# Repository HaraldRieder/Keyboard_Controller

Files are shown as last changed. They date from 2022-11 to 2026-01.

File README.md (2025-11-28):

## Tasteninstrument mit 6+6 Tastatur

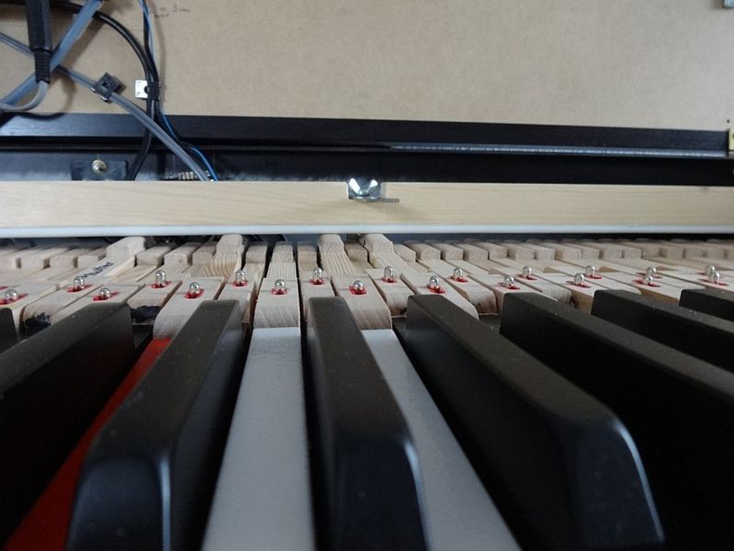
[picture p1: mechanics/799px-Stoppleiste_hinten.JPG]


Dieses Archiv enthält Anleitungen, Dokumentation und Quellcode zum Bau eines MIDI Instruments mit 6+6 Tastatur. 

Die Tastatur entspricht im vorderen Bereich der eines mechanischen Klaviers. Im hinteren Bereich kommen anstatt der Hammermechanik Bleigewichte und eine Stoppleiste zum Einsatz. Der [Bau der Tastatur ist hier](mechanics/README.md) beschrieben.

Die Elektronik basiert auf einem handelsüblichen Stummschaltesystem für Klaviere (QuietTime), das bereits Klangerzeugung enthält und MIDI-Signale ausgeben kann. Das ist für reines Klavierspiel vollkommen ausreichend. 

Ein Arduino Mega 2560 erweitert das Instrument um zusätzliche Regler, die Möglichkeit Presets für Sound Module abspeichern sowie ein Basspedal mit Diodenmatrix anschließen zu können. Die [Hardware ist hier](electronics/README.md) und die [Software und deren Bedienung hier](software/README.md) beschrieben.

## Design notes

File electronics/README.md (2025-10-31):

# Elektronik für die 6+6 Tastatur

## Module

Mit dem Hauptschalter des GT-2 mini schalten sich die komplette interne Elektronik sowie die beiden gesicherten Steckdosen auf der Rückseite mit ein und aus. Für diesen Komfort sorgt ein Triac-Relais mit Nulldurchgangsschaltung. Um es anzusteuern mussten 5V Versorgungsspannung aus dem Hauptmodul des GT-2 mini abgegriffen werden.

|Blockschaltbild|
| ----------- |
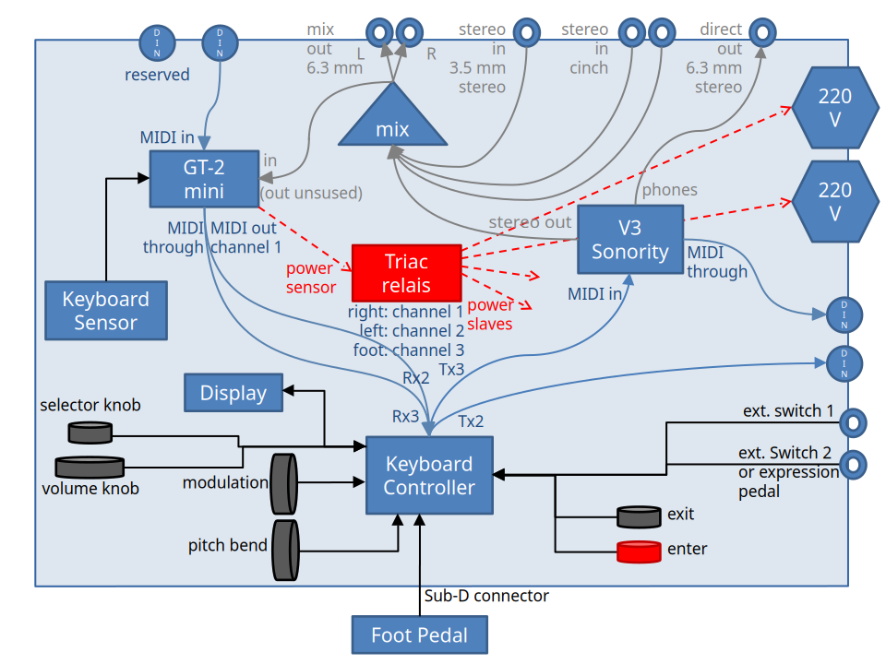
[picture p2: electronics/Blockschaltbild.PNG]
||

Das GT-2 mini Hauptmodul wird wie vorgesehen von der Tastatursensorleiste angesteuert und kann über seine Original-Bedieneinheit bedient werden. Pedalsensoren sind keine angeschlossen, denn Sustain, Sostenuto usw. werden über die selbstgebaute Steuerung realisiert. Die Tastendrücke gelangen als MIDI-Nachrichten zur selbstgebauten Steuerung, die auf einem Arduino Mega 2560 basiert. An der Steuerung hängt ein 2x20 Zeilen LCD Display, MIDI-Ein- und Ausgänge, 2 Handräder für Pitch Bend und Modulation, 2 Taster und optional extern: 1 Schalter, 1 Steuerpedal, 1 Basspedal.

Die Steuerung mischt die diversen Sensorinformationen zu den MIDI-Daten, die vom GT-2 mini empfangen worden sind, und leitet das Gesamtkunstwerk über MIDI an das interne V3 Sonority XXL Sound-Modul zwecks Hörbarmachung weiter.

Der MIDI-Eingang wird durch das GT-2 mini zur Steuerung geschleift. Diese mischt sie zum MIDI-Strom Richtung V3 hinzu. Dadurch kann das V3 als Sound-Modul über den zweiten Eingang z.B. von einem Sequenzer genutzt werden, während gleichzeitig auf der Tastatur dazu gespielt wird.

Zur Bedienung der Steuerung dienen 2 Regler (klein und groß), 2 Taster (rot und schwarz), die 2 Handräder, die Tastatur (z.B. Festlegung einer Split-Position durch Tastendruck) und optional ein Fußpedal.

Der Audio-Ausgang des V3 sowie 2 externe Stereo-Eingänge (Cinch und 3,5 mm Klinke) werden über den selbstgebauten Mischer geschleift zum externen Audio-Ausgang (2 x 6,3 mm Klinke) und gleichzeitig zum Eingang des GT-2 mini, wo das gemischte Signal über die anschließbaren Kopfhörer gehört werden kann.
Auch das Metronom des GT-2 mini kann auf diese Art benutzt werden.

Der Kopfhörer-Ausgang des V3 ist direkt nach außen geführt auf eine 6,3 mm Klinkenbuchse. Dieses Signal lässt sich außer in Kopfhörer auch in Standardeingänge einspeisen.

2024 wurde ein Ketron SD-2 durch das V3 Sonority XXL Modul ersetzt. Man konnte mit dem SD-2 keine Tremolos spielen, weil es dann Noten-Aussetzer bekam, und ein Software-Update war nicht mehr zu erwarten. Mit dem V3 kann man Tremolos spielen, so wie auf jedem mechanischen Klavier.

## Arduino Mega 2560 mit Peripherie

Zunächst einmal gab es da ein schönes Wersi-Basspedal, das anschließbar sein sollte - selbstverständlich ein 6+6 Pedal. Es hing [früher](https://github.com/HaraldRieder/Historic/index.html) an einer eigens dafür aufgebohrten Döpfer LMK3-Elektronik und enthält eine zum LMK3 passende Diodenmatrix.

|Die anzuschließende Diodenmatrix|
| ----------- |
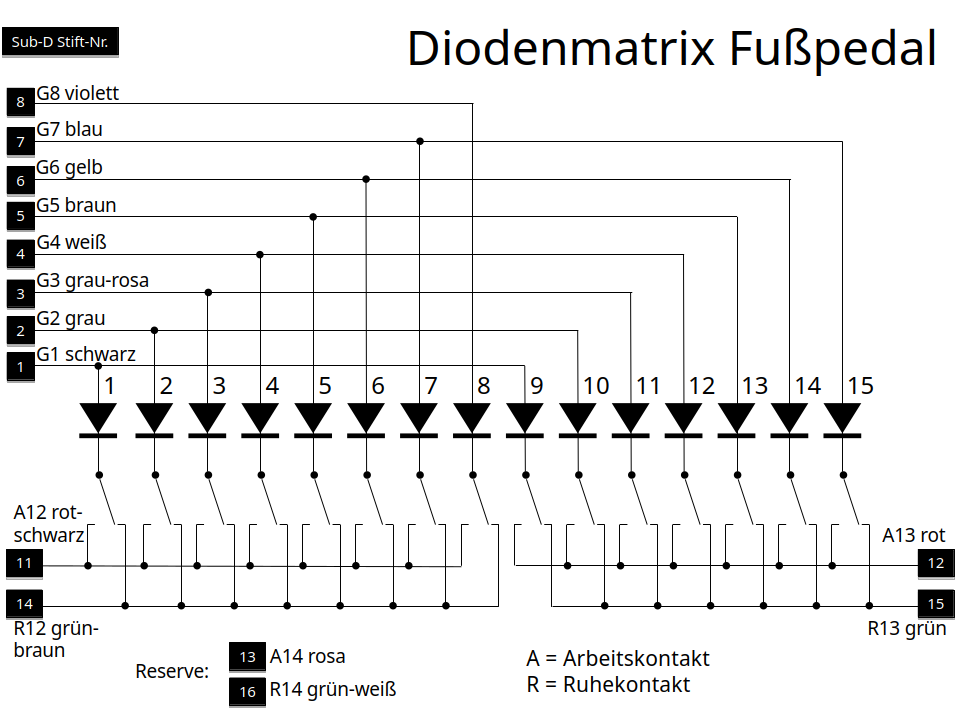
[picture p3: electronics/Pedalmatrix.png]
||

Deswegen finden sich im Schaltplan unten 6 Stück 1k Widerstände, die in LMK3-typischer Art geschaltet sind. Die Ansteuerung des Pedals gelang auf Anhieb. Ängste, dass Ladungen aus den Ausgängen eventuell nicht schnell genug übertragen werden könnten, bevor deren Wirkungen über die Eingänge der Matrix erfragt würden, erwiesen sich als unbegründet. Gegen solche Effekte hätte es aber ein Mittel gegeben: verzögertes Auslesen durch die Software.

Das Pedal wird mit einem Sub-D Stecker an das Pianogehäuse angeschlossen.

|Digitalteil mit Arduino Mega 2560|
| ----------- |
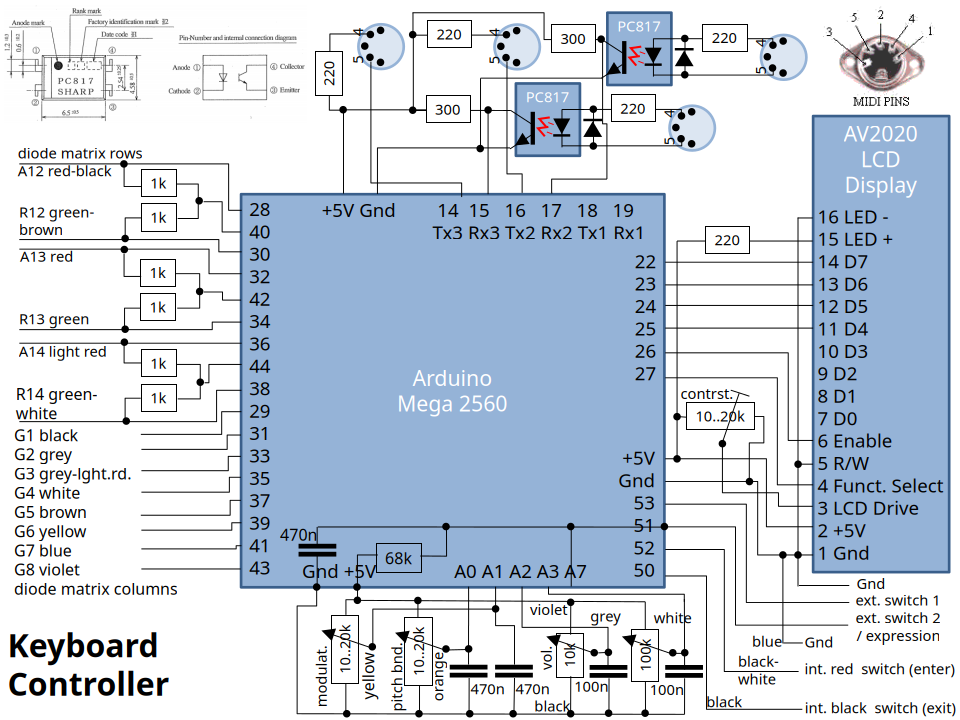
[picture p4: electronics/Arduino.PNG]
||

Über den Anschluß von MIDI-Peripherie und LCD-Anzeigen an Arduino-Boards gibt es haufenweise Anleitungen. Diese brauchen hier nicht wiederholt zu werden. Der Mega 2560 könnte bis zu 4 MIDI-Ein- und Ausgänge bedienen. Ich habe die Schaltung auf 2 MIDI-Ein- und Ausgänge ausgelegt.

_Der Digitalteil wurde ab Herbst 2015 nach und nach in Betrieb genommen. Im Frühjahr 2016 zeigten sich nach längerem Betrieb erstmals lustige Effekte: Aussetzer, falsche Tonhöhen, ganz andere Klangfarben als die eingestellte. So hören sich typischerweise MIDI-Bitfehler an, und da es in kaltem Zustand nach dem Einschalten nie Fehler gab, war klar, dass es ein Temperatureffekt sein musste. Der 220 Ohm Widerstand am MIDI-Eingang war etwas zu groß bemessen für den verwendeten PC 817 Optokoppler. Die Reparatur erfolgte durch Austausch des PC 817 gegen ein anderes Exemplar. Alternativ hätte man den Widerstand verkleinern können._

Die Handräder werden zwar von relativ niederohmigen Potentiometern abgegriffen, sind allerdings über lange Leitungen mit der Steuerung verbunden. Die 470 nF Glättungskondensatoren sind deswegen tatsächlich erforderlich! Ohne sie bekäme die Software von der Hardware nerviges Gezappel.

Für die internen Taster und externen Schalter werden Pullup-Widerstände eingesetzt. Damit gab es noch nie ein falsches Signal.

Ein externer Anschluss ist ein Zwitter. Sowohl ein analoger (A7) als auch ein digitaler Eingang (51) teilen sich ihn.
Während sonst Arduino-interne Pullup-Widerstände zum Einsatz kommen, ist hier ein externer Pullup-Widerstand Rp = 68k verbaut.
Der Grund: es sollte ein vorhandenes Schwellerpedal angeschlossen werden. Das Schwellerpedal enthält ein 450k logarithmierendes Poti.
Die Software soll nicht linearisieren müssen. Das Poti liefert einen exponentiell vom Weg x abhängigen Widerstand R(x).
Durch den Spannungsteiler aus Pullup Rp und R ergibt sich eine Eingangsspannung U(R) ~ R/(R+Rp).
Durch geschickte Wahl von Rp kann man die verketteten nichtlinearen Funktionen R(x) und U(R)
gegeneinander ausspielen und so die Gesamtfunktion U(R(x)) = U(x) einigermaßen linear bekommen.
Die Entscheidung, ob der Anschluss für kontinuierliche oder diskrete MIDI Controller oder beide Arten zugleich verwendet wird, fällt erst in der Software.

Später wurden 2 Potentiometer auf der rechten Seite der Frontblende hinzugefügt. Beide sind an analoge Eingänge angeschlossen.
Eines davon regelt immer die Gesamtlautstärke.

Es sind noch 3 analoge Eingänge unbeschaltet.

Das nächste Bild zeigt den Teil der Elektronik, der am aufklappbaren Deckel des Pianogehäuses hängt:

- links noch mit Ketron SD-2 Sound-Modul
- rechts Steuerung mit Arduino Board. Der Klinkenstecker kommt von den beiden Mono-Klinkenbuchsen für die externen Schalter. Der graue Stecker rechts führt zur Pedalanschlussbuchse (Sub-D).
- oben 2x20 zeilige LCD-Anzeige
- rechts neben dem Arduino pressspänerne Leere: später hat sich an diese Stelle der Audio-Mischer hinzugesellt.

|Elektronik im Deckel|
| ----------- |
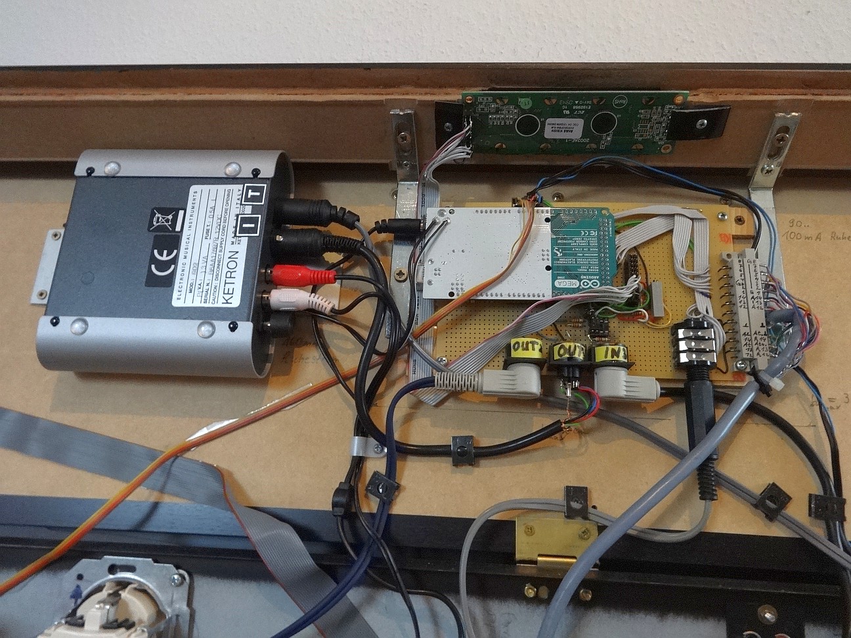
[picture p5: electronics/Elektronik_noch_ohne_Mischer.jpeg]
||

Viel mehr ist zum Digitalteil nicht zu sagen, den Rest muss die Software erledigen.

## Audio-Mischer

Der Audiomischer hat zunächst ein eigenes Analognetzteil mit Transformator und Brückengleichrichter bekommen, um nicht auf unerwünschte Weise mit dem Digitalgedöns verbunden sein zu können (Brummschleife!). Ein 7809 Spannungsregler regelt auf 9V, was für viele Operationsverstärker ausreicht.

Es kommt ein Operationsverstärker TLE2072 zum Einsatz, der rauschärmer als ein TL072 sein soll.

|Schaltplan Audio-Mischer|
| ----------- |
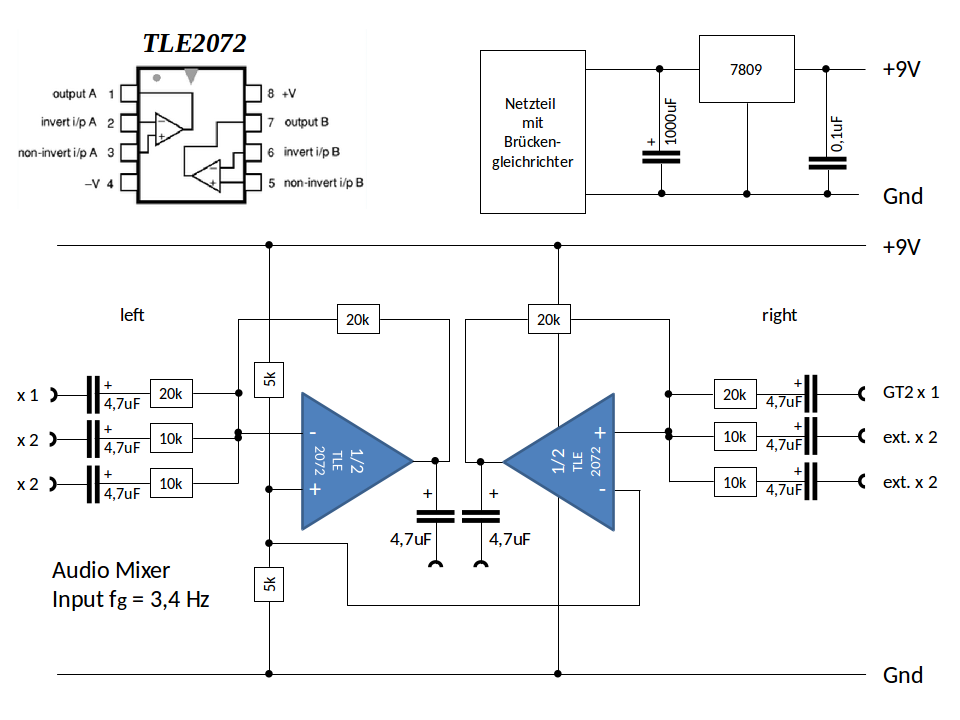
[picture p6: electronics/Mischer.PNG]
||

Der Mischer "verstärkt" den für das MIDI-Modul vorgesehenen Stereo-Kanal mit dem Faktor 1. Der Lautstärkeregler des V3 ist immer voll aufgedreht. Die beiden externen Stereo-Kanäle werden mit einem Faktor 2 verstärkt. Das soll es erlauben, das interne Sound-Modul bei Bedarf zu übertönen.
Der Stereo-Ausgang ist nach außen geführt und auf den Eingang des GT-2 mini gelegt. Dort darf man das Eingangssignal nicht ganz aufdrehen, weil es sonst zu Übersteuerungen kommt.

|Der Mischer entsteht|
| ----------- |
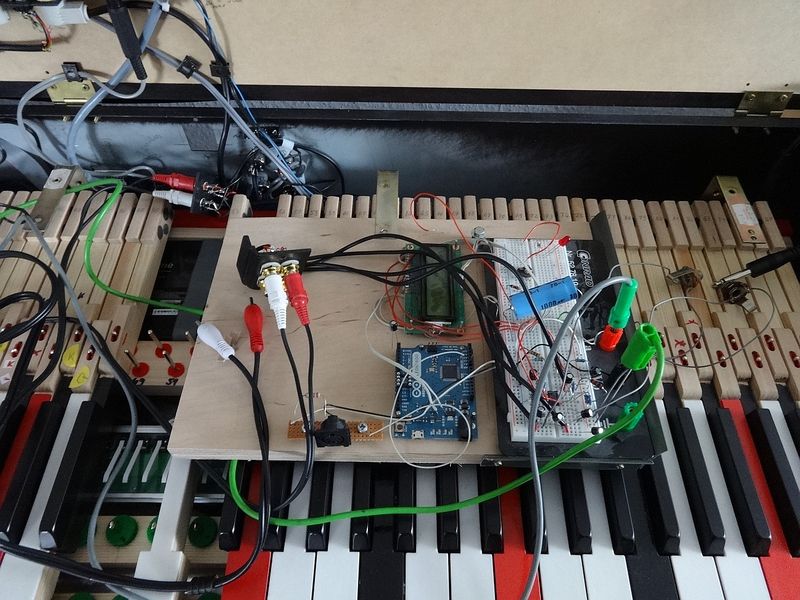
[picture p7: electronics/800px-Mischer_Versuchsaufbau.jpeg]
||

Der Mischer wurde zunächst auf einem Experimentierbrett aufgebaut. Dabei gab es keine Überraschungen, außer dass ich in einem Anfall von geistiger Umnachtung zuerst den Spannungsregler nicht eingeplant hatte und mit entsprechendem Gebrumme bestraft wurde.

|Master-Slave-Switch und Mischer-Netzteil|
| ----------- |
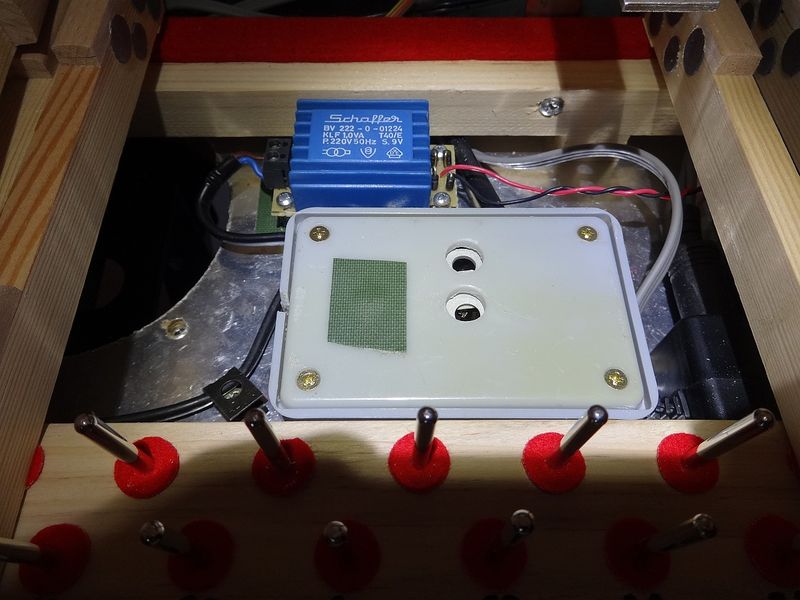
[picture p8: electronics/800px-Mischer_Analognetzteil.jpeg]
||

Das Bild zeigt das graue Gehäuse des Master-Slave-Netzschalters und das daran angeschlossene Netzteil für den Mischer mit seinem blauen Transformator und 4 1N4006 Dioden in Brückenschaltung.

## Alles zusammen

|Elektronik untergebracht, noch ohne Mischer|
| ----------- |
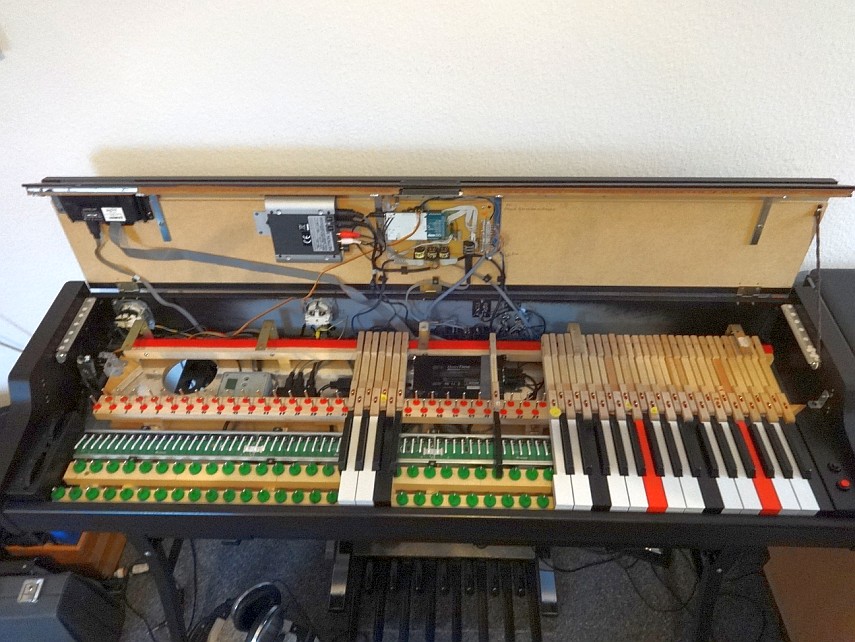
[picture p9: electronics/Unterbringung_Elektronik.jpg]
||

|Mischer und neue Bedienelemente an der Frontblende|
| ----------- |
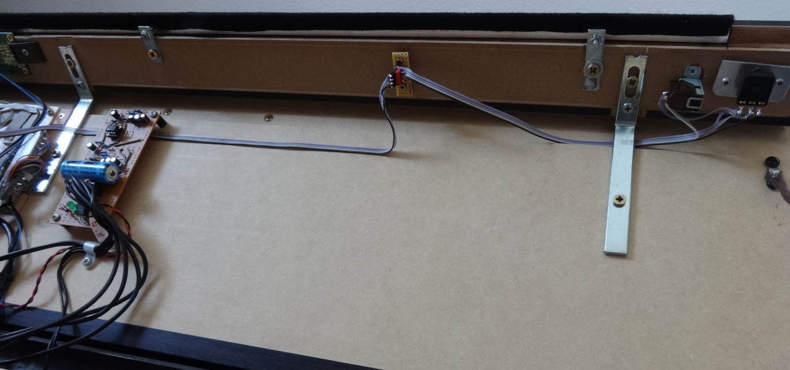
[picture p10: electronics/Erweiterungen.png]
||

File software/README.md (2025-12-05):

# Weichware

Der Quellecode für das Arduino Mega 2560 Board ist [auf GitHub](https://github.com/HaraldRieder/Keyboard_Controller) verfügbar.

Das Board verfügt über 8 KByte Hauptspeicher (RAM) und 4 KByte EEPROM,
in dem die duch den Bediener vorgenommenen Einstellungen dauerhaft gespeichert werden.

Aktuell wird davon ausgegangen, dass ein V3 Sonority XXL angesteuert werden soll (`SonorityXXL.h`).
Davor war die Software zur Steuerung eines Ketron SD2 ausgelegt (`KetronSD2.h`).

Der Quellcode lässt sich mit vertretbarem Aufwand an andere MIDI Module anpassen.
Nicht jedes Modell bietet dieselben Funktionen an,
doch die Unterstützung vieler Standard-MIDI-Funktionen ist heutzutage weit verbreitet.
Unterschiede finden sich naturgemäß im Sysex-Bereich.

## Initialisierung

Aktuell werden 35 Presets unterstützt.
Wird ein Preset gelesen und dabei nicht der "magische" 32-Bit-Wert `2e031fe5` gefunden, dann wird es mit Standardeinstellungen initialisiert:
das Pedal arbeitet als Steuerpedal (Controller) und der Tastaturbereich ist nicht geteilt (Split).
Auf diese Weise kann ein neues Board in Betrieb genommen werden.

## Backups

Es gibt keine Backup-Funktion (z.B. MIDI-Dumps).
Als primitiver Ersatz werden die Einstellungen nach dem Einschalten auf USB in menschenlesbarem Format ausgegeben.
Um sie zu sehen benötigt man eine Arduino IDE mit seriellem Monitor.
Das Arduino-Board muss an den Rechner per USB-Kabel angeschlossen sein.
Die Baud-Rate muss auf **500000** eingestellt sein.
Dann zeigt sich nach dem Einschalten im seriellen Monitor etwas wie im folgenden Beispiel.

      Global_Settings
       Velocity map: 77
      Presets
      1 Reverb type: Room 1, Effect type: Chorus 1
        Keyboard:   Piano / Class Gnd Res
          Transpose: 0, Fine tune: 0, Volume: 100, Stereo pan: 64, Reverb send: 10, Effects send: 0
          Cutoff frequency: 33, Resonance: 0, Attack: 64, Decay: 64, Release: 64
          Vibrato rate: 64, Depth: 0, Delay: 64, Portamento time: 1
          Modulation wheel: modulation, Pitch wheel: pitch bend, External switch: sustain, External pedal: cutoff frq
      2 Reverb type: Room 2, Effect type: Chorus 3
        Keyboard:   E-Pno / MK1
          Transpose: 0, Fine tune: 0, Volume: 84, Stereo pan: 64, Reverb send: 5, Effects send: 39
          Cutoff frequency: 82, Resonance: 0, Attack: 64, Decay: 64, Release: 64
          Vibrato rate: 64, Depth: 0, Delay: 64, Portamento time: 1
          Modulation wheel: modulation, Pitch wheel: pitch bend, External switch: sustain, External pedal: (none)
      ...
      35 Reverb type: Room 1, Effect type: Chorus 1
        Foot Pedal:   Bass / Up Jz no fingr
          Transpose: 2, Fine tune: -2, Volume: 110, Stereo pan: 64, Reverb send: 0, Effects send: 0
          Cutoff frequency: 64, Resonance: 0, Attack: 64, Decay: 64, Release: 74
          Vibrato rate: 64, Depth: 0, Delay: 64, Portamento time: 255
          Modulation wheel: (none), Pitch wheel: (none), External switch: (none), External pedal: (none)
        Keyboard Left:   Organ / __853____ slow
          Transpose: 12, Fine tune: 0, Volume: 55, Stereo pan: 64, Reverb send: 15, Effects send: 0
          Cutoff frequency: 22, Resonance: 0, Attack: 64, Decay: 64, Release: 64
          Vibrato rate: 64, Depth: 0, Delay: 64, Portamento time: 255
          Modulation wheel: modulation, Pitch wheel: pitch bend, External switch: sustain, External pedal: (none)
        Keyboard Right:   Organ / 8________ slow
          Transpose: -12, Fine tune: 2, Volume: 100, Stereo pan: 64, Reverb send: 15, Effects send: 0
          Cutoff frequency: 127, Resonance: 0, Attack: 64, Decay: 64, Release: 64
          Vibrato rate: 64, Depth: 0, Delay: 64, Portamento time: 255
          Modulation wheel: modulation, Pitch wheel: pitch bend, External switch: sustain, External pedal: inv.expres
        Keyboard Right Layer:   Organ / 6876_____ fast
          Transpose: -12, Fine tune: 0, Volume: 127, Stereo pan: 64, Reverb send: 15, Effects send: 0
          Cutoff frequency: 64, Resonance: 0, Attack: 64, Decay: 64, Release: 64
          Vibrato rate: 64, Depth: 0, Delay: 64, Portamento time: 255
          Modulation wheel: modulation, Pitch wheel: pitch bend, External switch: sustain, External pedal: expression
      Demian ready

## Latenzen

Nach dem Verlassen der globalen Einstellungen (siehe Bedienung) werden kurz Zeiten eingeblendet, die zur Latenz beitragen:

- Loop delay: die Zeit, die das Arduino Board für seine eigenen Geschäfte benötigt, bevor es wieder die Kontrolle an den Anwendungscode abgibt
- Pedal scan: die Zeit, die für das einmalige Ermitteln der Stellung der 15 Pedaltasten benötigt wird

Die Zeiten werden zyklisch gemessen. Angezeigt werden die jeweils gemessenen Maximalwerte. In Summe bewegen sie sich um oder unter 1 ms.

Zum Vergleich: bei 31250 baud (Bit/s) kann man über eine klassische MIDI-Verbindung in 1 ms wieviel Note-on oder Note-off Nachrichten übertragen?
Jede solche Nachricht benötigt 3 Byte. Jedes Nutz-Byte wird dank Start- und Stopbit auf 10 Bit vergrößert, wodurch jede solche Nachricht 30 Bit lang wird.
Also kann man in einer Millisekunde 0,001 x 31250 / 30 = eine einzige MIDI-Nachricht übertragen.

Bei kontinuierlichen Reglern kann es aufgrund von Rauschen (mechanisch, thermisch) zu häufigen Änderungen der digitalisierten Werte kommen,
die das Potential dazu haben, einen MIDI-Kanal zu verstopfen. Die Software verfügt über Mechanismen zur Rauschunterdrückung.

## Bedienung

### Bedienelemente

- schwarzer Taster: Durchwechseln, Ausgang, Abbruch
- roter Taster: Eintritt, Bestätigen
- kleiner Regler: Auswahl von Parameterwerten
- großer Regler: Gesamtlautstärke
- Tonhöhenrad: zur Beeinflussung der Tonhöhe (Pitch bend) oder je nach Preset auch anderer MIDI-Controller. Wenn ein Preset editiert wird, dann werden mit diesem Rad Parameterwerte eingestellt.
- Modulationsrad: steuert den Vibratoeffekt (Modulation) oder je nach Preset auch andere MIDI-Controller. Wenn ein Preset editiert wird, dann werden mit diesem Rad einzustellende Parameter ausgesucht.
- Pedal: ein 15-Tastenpedal kann wahlweise als Basspedal oder zur Steuerung von MIDI-Controllern verwendet werden.
- externer Schalter: standardmäßig für ein Haltepedal (Sustain) vorgesehen, kann je nach Preset auch andere MIDI-Controller beeinflussen.
- externer Regler: standardmäßig für den Ausdruck vorgesehen (Expression), kann je nach Preset auch andere MIDI-Controller beeinflussen.

Viele MIDI-Module interpretieren *Expression* einfach als Lautstärke. Manchmal lässt sich etwas anderes einstellen.

### Einschalten

Beim Einschalten wird für wenige Sekunden der noch freie Speicher (RAM) angezeigt.

Außerdem wird automatisch ermittelt, ob der externe Schalter als Öffner oder Schließer arbeitet.
Damit dies gelingen kann, sollte der Schalter beim Einschalten in seiner Ruheposition sein.
Das Ergebnis wird ebenfalls für wenige Sekunden angezeigt.

Nach dem Einschalten wird das Preset geladen und angezeigt, das der Stellung des kleinen Reglers entspricht.

### Spielmodus und globale Einstellungen

Mit dem schwarzen Taster kann zyklisch gewechselt werden zwischen

- Spielen von Presets, mit den zuvor frei gewählten und gespeicherten Einstellungen und gegebenenfalls Keyboard-Split und Fußpedal
- Spielen von Sounds, wie sie bereits der Hersteller im V3 Modul festgelegt hat
- Globale Einstellungen

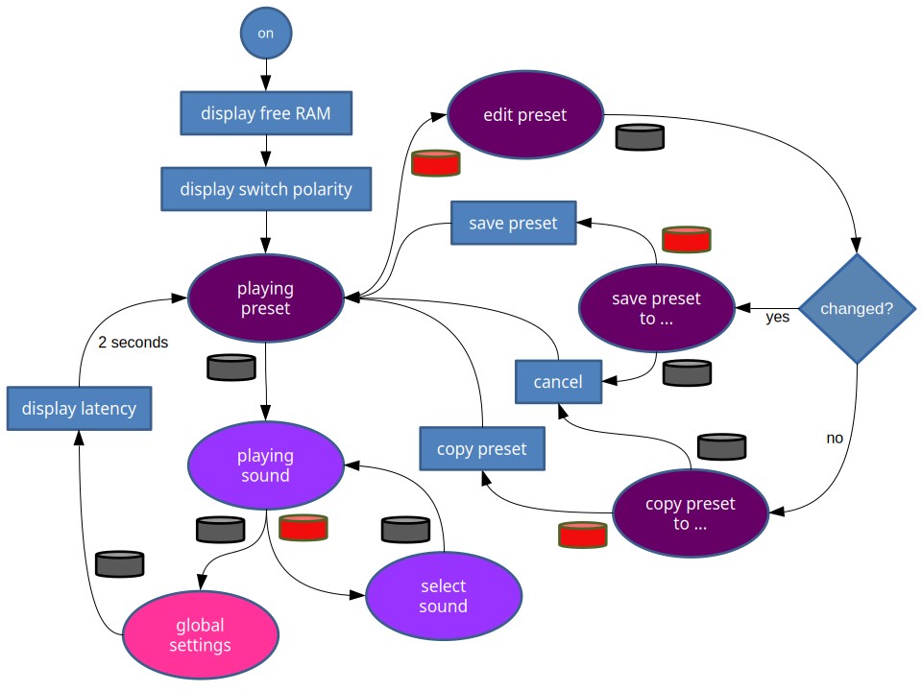
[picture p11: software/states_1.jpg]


Aus dem Modus *Spielen von Presets* gelangt man in den Editier-Modus durch Drücken des roten Tasters, den man mit dem schwarzen Taster wieder verlassen kann.

Wurde das Preset verändert, so wird man gefragt, ob man das Preset speichern möchte. Standardmäßig wird es an die aktuelle Position gespeichert. Mit dem Modulationsrad lässt sich jedoch eine anderes Ziel wählen, das heißt, dass das editierte Preset nicht geändert wird sondern ein anderes Preset überschrieben wird. Der rote Taster bestätigt das Speichern. Mit dem schwarzen Taster lassen sich die Änderungen verwerfen.

Wurde das Preset nicht verändert, so wird man gefragt, ob man das Preset kopieren möchte. Mit dem Modulationsrad lässt sich das Ziel für die Kopieraktion wählen. Der rote Taster bestätigt das Kopieren. Mit dem schwarzen Taster lassen sich die Änderungen verwerfen.

Nochmaliges Drücken des schwarzen Tasters wechselt in den Modus _Spielen von Sounds_. Mit dem kleinen Regler wird nun der Sound innderhalb der Bank gewählt. 

Nach Drücken des roten Tasters gelangt man in den Modus _Auswahl eines Sounds_ und Modulations- und Tonhöhenrad dienen zur Auswahl von Bank bzw. Sound. 
Dabei blinkt die Anzeige. Drücken des schwarzen Tasters wechselt zurück in den Modus _Spielen von Sounds_, das Blinken hört auf.

### Editieren eines Preset

Ein Preset besteht aus vielen Parametern, die in Gruppen zusammengefasst sind. Die Gruppe lässt sich mit dem Modulationsrad auswählen. Es gibt diese Gruppen:

- Gemeinsame Parameter
- Tastatur-Parameter (wenn Tastatur nicht geteilt)
- Pedal-Parameter (nur im Pedalmodus *Bass*)
- Parameter für linken Tastaturabschnitt (nur wenn Tastatur geteilt)
- Parameter für rechten Tastaturabschnitt (nur wenn Tastatur geteilt)
- Parameter für rechten Tastaturabschnitt (zweite Klangschicht, nur wenn Tastatur geteilt)

Die Parameter in den Gruppen werden mit dem Modulationsrad ausgewählt. Parameterwerte können mit dem Tonhöhenrad oder dem Regler eingestellt werden.

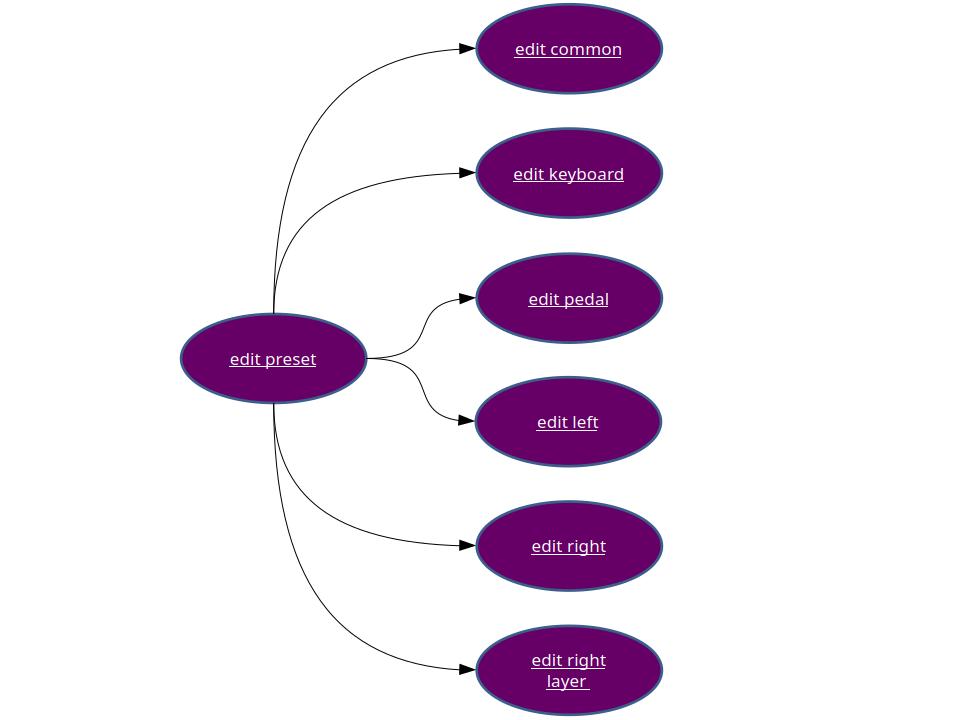
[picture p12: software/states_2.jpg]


#### Gemeinsame Parameter

- Tastaturtrennung links/rechts (Split-Position). Die Position lässt sich auch durch Drücken einer Taste der Tastatur einstellen. Zum Aufheben der Trennung muss das Modulationsrad oder der Regler bemüht werden.
- Pedal-Modus: Wahl zwischen Bass- oder Fußschalter-Modus
- Typ des 1. Effektgeräts (FX1)
- Typ des 2. Effektgeräts (FX2)

#### Tastatur-Parameter, Pedal-Parameter, Parameter für Tastaturabschnitte

Diese Gruppen enthalten immer denselben Satz an Parametern:

- Sound Bank
- Sound (MIDI-Programm-Nummer)
- Transponierung in "Halbton"-Schritten
- Feinstimmung in Cent-Schritten
- Relative Lautstärke
- Stereo-Panorama
- Hall (1. Effektgerät)
- Effekt (2. Effektgerät)
- Tiefpass-Frequenz (Cutoff)
- Filter-Resonanz
- Ankling-Geschwindigkeit (Attack)
- Abkling-Geschwindigkeit vor dem Loslassen der Taste (Decay)
- Abkling-Geschwindigkeit nach dem Loslassen der Taste (Release)
- Vibrato-Frequenz (Rate)
- Vibrato-Stärke (Depth)
- Vibrato-Verzögerung (Delay)
- Portamento-Zeit. Portamento muss über ein Bedienelement explizit eingeschaltet werden.
- Funktion der Pitch-Bend-Rads:
    - keine
    - Pitch Bend
    - Portamento-Einsatz
- Funktion des Modulations-Rads
    - keine (none)
    - Modulation
    - Tiefpass-Frequenz (Cutoff)
    - Filter-Resonanz
    - Expression
    - Expression invertiert
- Funktion des externen Schalters
    - keine (none)
    - Haltepedal (Sustain)
    - Sostenuto
    - Weich (Soft)
    - Portamento an/aus
- Funktion des externen Reglers
    - keine (none)
    - Modulation
    - Tiefpass-Frequenz (Cutoff)
    - Filter-Resonanz
    - Expression
    - Expression invertiert

Die *keine* Funktion kann z.B. dazu genutzt werden, ein Haltepedal nur auf den rechten Tastaturbereich wirken zu lassen,
wenn der linke Bereich dem Bassspiel dienen soll.

Die Funktion _Expression invertiert_ ist speziell für den rechten Tastaturbereich gedacht, der 2 Kanäle gleichzeitig ansteuert.
Wenn ein Kanal mit _Expression_ und der andere mit _Expression invertiert_ vom selben Regler
gesteuert wird, lassen sich damit Überblendungen realisieren.

### Pedal

Das Pedal dient entweder zum Bassspiel, wenn es in den Preset-Einstellungen so definiert ist, oder zur Steuerung der Funktionen, die auf dem Bild gezeigt sind. Soft, Sustain (Haltepedal) und Sostenuto sind von Klavieren her bekannt. Wenn im Preset-Modus ein Tastatursplit aktiv ist, dann können Sustain und Sostenuto für linken und rechten Klaviaturbereich getrennt gesteuert werden. Unterstützung von Portamento hängt vom gewählten Sound des angesteuerten MIDI-Moduls ab.

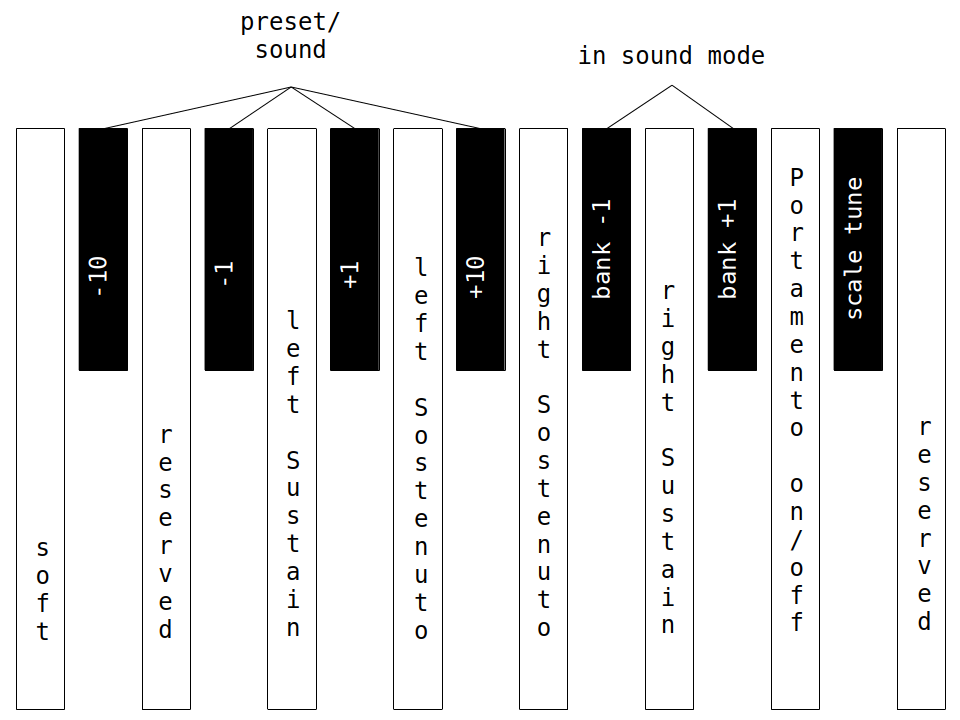
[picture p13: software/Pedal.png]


Mit den linken 4 kurzen Pedalen lassen sich Presets oder Sounds in 10er- oder 1er-Schritten weiterschalten. Eine weitere Funktion ist das Wechseln der Bank im Sound-Modus.

#### Scale Tune

Mit Hilfe dieses Pedals lassen sich verschiedene Feinstimmungen wählen.
Wird das Pedal gedrückt, dann wird die gewählte Feinstimmung angezeigt.
Mit gleichzeitigem Betätigen einer Taste wird eine neue Feinstimmung gewählt.
Die Feinstimmung wird immer global verwendet, d.h. für das Basspedal und alle Tastatur-Bereiche.

In der europäischen Musik ist es üblich, aufeinanderfolgende Tasten im Frequenzverhältnis 2 hoch (1/12) zu stimmen. Dies ist die Normaleinstellung aller handelsüblichen MIDI-Module und -Synthesizer.
Durch diese Wahl wird nach 12 Tasten ein Naturtonintervall erreicht: die "Oktave" mit einem Frequenzverhältnis von 2. Andere Naturtonintervalle können nur näherungsweise erreicht werden: die "kleine Terz" (6/5), die "große Terz" (5/4), die "Quarte" (4/3), die "Quinte" (3/2), usw. Während die Quinten und Quarten gut angenähert werden, gibt es bei den Terzen eine deutlich hörbare Schwebung.

Eine andere Näherungsstimmung, die mitteltönige (meantone) Stimmung, teilt die "Oktave" statt in 12 in 31 gleiche Frequenzverhältnisse. Aufeinanderfolgende Tasten sind in einem Vielfachen von 2 hoch (1/31) gestimmt. Mangels Tasten konventioneller Tastaturen lassen sich nur 12 der 31 Töne (je "Oktave") zum Klingen bringen. Die Wahl des Grundtons bestimmt, welche 12 dieser 31 Töne zu hören sind. Der Vorteil dieser Stimmung ist die bessere Näherung an die Naturton-Terzen, während Quarten und Quinten etwas schlechter erreicht werden.

Die Naturtonstimmung (clean) verwendet reine "Oktaven", "Quinten" und "große Terzen" zum Aufbau aller Intervalle ausgehend vom Grundton, d.h. die Frequenzverhältnisse 2, 3/2 und 5/4. Reine Quarten und kleine Terzen werden automatisch erreicht, da z.B. 4/3 = 2 / (3/2).

Die Naturtonstimmung gibt es in einer symmetrischen Variante, bei der der Tritonus "normal" gestimmt bleibt.

Weiter zur Auswahl stehen eine exotischere Naturtonstimmung aufgebaut aus 7/6 ("Septimen") statt 5/4 ("Terzen") und eine aus dem arabischen Kulturraum stammende Stimmung.

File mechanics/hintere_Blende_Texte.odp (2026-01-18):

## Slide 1

R In

L In

MIDI In

n.c.

Switch

Control

Stereo In

V3 Out

MIDI Out 1

MIDI Out 2

Foot Pedal

R Mix Out L

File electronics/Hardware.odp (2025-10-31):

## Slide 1

exit

enter

modulation

pitch bend

L

R

volume knob

DIN

DIN

mix

out
6.3 mm

stereo

in

3.5 mm

stereo

stereo

in

cinch

direct

out

6.3 mm

stereo

reserved

mix

220V

MIDI in

in

GT-2

mini

(out unsused)

power

sensor

phones

220V

MIDI

through

MIDI out

channel 1

Triac

relais

right: channel 1
left: channel 2
foot: channel 3

Tx3

stereo out

power

slaves

V3

Sonority

MIDI in

MIDI

through

Keyboard
Sensor

DIN

selector knob

Display

Rx2

DIN

Keyboard

Controller

Rx3

Tx2

ext. switch 1

ext. Switch 2
or expression
pedal

Sub-D connector

Foot Pedal

## Diodenmatrix Fußpedal

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
Sub-D Stift-Nr.

8

G8 violett

7

G6 gelb

G7 blau

6

5

G5 braun

4

G3 grau-rosa

G4 weiß

3

2

G2 grau

1

G1 schwarz

A12 rot-

schwarz

A13 rot

11

12

R12 grün-

braun

14

13

A14 rosa

A = Arbeitskontakt

R = Ruhekontakt

R13 grün

15

Reserve:

16

R14 grün-weiß

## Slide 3

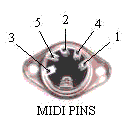
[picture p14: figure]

10k

AV2020

LCD

Display

16 LED -

15 LED +

14 D7

13 D6

12 D5

11 D4

10 D3

9 D2

8 D1

7 D0

6 Enable

5 R/W

4 Funct. Select

3 LCD Drive

2 +5V

1 Gnd

Arduino

Mega 2560

22

23

24

25

26

27

14 15 16 17 18 19

Tx3 Rx3 Tx2 Rx2 Tx1 Rx1

+5V

Gnd

53

51

52

50

Gnd +5V A0 A1 A2 A3 A7

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
+5V Gnd

pitch bnd.

modulat.

orange

10..20k

10..20k

yellow

1k

1k

1k

1k

PC817

5 4

5 4

220

5 4

PC817

5 4

vol.

100k

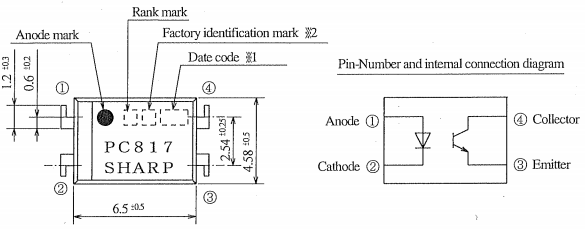
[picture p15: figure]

220

300

220

300

220

diode matrix rows

A12 red-black

R12 green-

brown

A13 red

1k

1k

220

R13 green

A14 light red

R14 green-

white

G1 black

G2 grey

G3 grey-lght.rd.

G4 white

G5 brown

G6 yellow

G7 blue

G8 violet

diode matrix columns

Keyboard

Controller

contrst.

10..20k

470n

68k

ext. switch 1

ext. switch 2
/ expression

int. red switch (enter)

Gnd

violet

grey

white

blue

black-
white

Gnd

470n

470n

black

100n

100n

black

int. black switch (exit)

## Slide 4

1/2

TLE 2072

+

20k

+

4,7uF

10k

+

4,7uF

10k

+

4,7uF

+

4,7uF

10k

+

4,7uF

10k

+

4,7uF

5k

5k

+

4,7uF

+

4,7uF

0,1uF

+

1000uF

1/2

TLE 2072

+

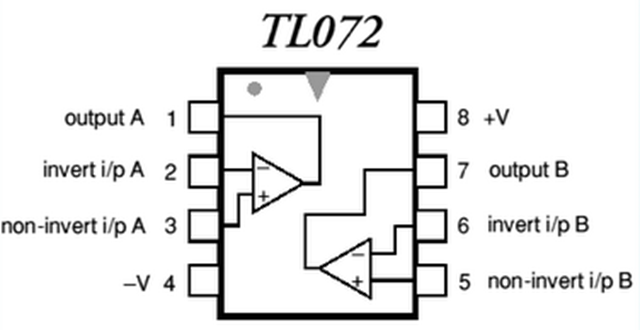
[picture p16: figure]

TLE2072

Netzteil

mit

Brücken-gleichrichter

7809

+9V

Gnd

+9V

left

20k

20k

right

x 1

x 2

x 2

20k

GT2 x 1

ext. x 2

ext. x 2

+

4,7uF

+

4,7uF

Audio Mixer

Input fg = 3,4 Hz

Gnd

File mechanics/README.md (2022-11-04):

# 6+6 Tastatur

## Ausgangslage

Eine FATAR-Tastatur mit Döpfer LMK3-Elektronik in einem Roland Digitalpiano-Oberteil, [selbst umgerüstet](https://github.com/HaraldRieder/Historic/index.html) von 7+5 auf 6+6. Im Vergleich zu einem mechanischen Klavier ist das Spielgefühl darauf deutlich unpräziser. Ich wollte etwas Besseres haben.

(Achtung: der MIDI File Printer hinter dem Link oben ist veraltet, der aktuellste liegt auf [GitHub](https://github.com/HaraldRieder/MIDIprt).)

## Kaufversuche

Sehr hilfsbereit war Dr. Pfeiffer, Geschäftsführer der gleichnamigen Flügel- und Klavierfabrik in Leonberg bei Stuttgart; nur leider nicht Tastaturfabrik: die Firma Pfeiffer kauft ihre Tastaturen fertig ein. Dr. Pfeiffer schlug vor, eine Tastatur spezialanfertigen zu lassen und darauf eine Flügelmechanik zu setzen. Das wäre schon das Non-Plus-Ultra in Sachen Spielgefühl geworden, doch angesichts von 3000 € Kosten allein für die Flügelmechanik sowie deren Ausmaßen habe ich diese Möglichkeit verworfen. Auch die Vorstoße bei den Tastaturlieferanten schienen preislich in diese Richtung zu zeigen (nur für die Tastatur), wobei nicht klar war, was man sonst noch für Kompromisse hätte eingehen müssen.

Eine Anfrage bei Schimmel, wo [Johannes Beyreuther](http://www.beyreuther-musikprinzip.de/) einst sein 6+6 Klavier spezialanfertigen lassen hatte, versandete trotz Nachhakens. Dr. Pfeiffer hatte gemeint, wenn schon eine Zeichnung existierte, dann wäre der Aufwand für so eine Spezialanfertigung wesentlich geringer.

Dann lernte ich, dass Klaviertasten Knicke haben, weil die Hammermechanik breiter als die Tastatur ist: je länger die Taste, desto weniger Verkantungsgefahr. Ich wollte eigentlich keine Mechanik. Und ich wollte keine unnötigen Knicke.

Schließlich kam ich zur Entscheidung, selbst eine Klaviatur zu bauen.

## Selbstbau
### Studium

Dazu musste ich erst einmal lernen, wie man eine richtige Klaviertastatur baut. Ich ging in die Stuttgarter Stadtbibliothek und lieh mir alle brauchbaren Bücher zum Thema aus (3 Stück). Danach wusste ich, welche Teile und Werkzeuge ich brauchen würde.

### Vorrecherche

Als Nächstes musste herausgefunden werden, ob die benötigten Teile überhaupt für Endverbraucher zu kaufen sind. Das sind sie, z.B. online bei [Meyne](https://shop.meyne.com/) oder bei [FTP](http://ftppianoforti.com/it/index). FTP schien insgesamt etwas preisgünstiger zu sein. Aber die Teile würden irgendwo zwischen 200 € und 300 € kosten, wobei ich mir die Klaviaturdruckzange erst mal verkneiffen musste, vielleicht würde es ja ohne gehen. Sie kostet allein mindestens 90 €, je nach Modell. Dazu käme natürlich das Holz, aber das gäbe es aus dem Baumarkt zu einem vernachlässigbaren Preis. An normalem - d.h. nicht Klavierbauspezial - Werkzeug fehlte mir: ein Bohrmaschinenständer mit Maschinenschraubstock, ein Fräskopf (für die Garnierungsvertiefung) und vielleicht noch ein paar Kleinigkeiten wie Holzbohrer in genau den richtigen Durchmessern für die Waagebalkenstifte oder die Tastaturvorderstifte.

Die schwarzen Obertastenbeläge waren freilich auch zu kaufen. Nur bräuchte ich 2 Sätze à 36 Stück, da eine 6+6 Klaviatur mehr schwarze Tasten als eine 7+5 Tastatur hat. Doch woher sollte ich die weißen Tastenbeläge nehmen? Die gab es nur oktavweise zu kaufen, davon hätte ich höchstens die D-Taste brauchen können. Ich hätte 44 Oktaven für 44 D-Tasten kaufen müssen! Viel zu teuer!! Die andere Alternaive wäre gewesen, die Beläge selbst zu sägen. Dazu wären eine Bandsäge und eine Poliermaschine notwendig geworden. Das klang nach viel Arbeit mit zweifelhaftem Resultat.

Aber vielleicht ginge es auch per 3D-Druck? Ja, es ginge! Ein grobes erstes Modell war mit Hilfe von [Tinkercad](https://www.tinkercad.com/) schnell erstellt. Dieses hochgeladen zu [Trinckle](http://www.trinckle.com/) lieferte gleich den zu erwartenden Preis: bei entsprechender Stückzahl je Druckvorgang um die 6 € je Tastenober- + Vorderbelag, also je Untertaste. Mit Infiltrierung würden die Tastenbeläge abriebfest sein. Dafür könnte ich selbst mit Epoxydharz sorgen. Epoxydharz gibt es z.B. bei Conrad.

Dann fehlten mir nur noch die Töne. Ein stummes Instrument mit schöner Tastatur wäre nicht wirklich genial. Da das Instrument transportabel bleiben sollte, kam nur Elektronik in Frage. Die Lösung wäre ein QuietTime GT-2 mini von [PianoDisk](http://www.pianodisc.eu/) hauptsächlich in der Funktion als Tonabnehmer. Wie ich inzwischen weiß, sind die Sounds: naja. Der mitgelieferte Kopfhörer gibt ihnen vollends den Rest! Der Roland JV-1010 wird also weiterhin als Klangerzeuger zum Einsatz kommen (und das wunderbare Cembalo aus dessen Super Sound Set). Das GT-2 mini würde das teuerste Teil des Projekts: 1300 € mit DIN MIDI-Adapter. Ich bestellte es bei Hr. Hermann, Inhaber des gleichnamigen Klavier- und Flügelhandels, in Möglingen. Er lieferte mir auch fertig garnierte Klaviaturbäckchen. Diese komplett selbst zu bauen schien mir doch zu kitzlig. Bei FTP könnte man sie aber auch kaufen. Hr. Hermann gab mir außerdem ein paar ausrangierte schwarze und weiße Tasten mit, damit ich diese genauer studieren konnte.

Alles in allem würde die Tastatur auf knapp 2000 € kommen. Bei einer Nutzungsdauer bis zu meinem Lebensende ein vertretbarer Preis.

### Planung

Die Planung startete mit dem Ausmessen der Tasten meines Juno-D, LMK3 sowie denen des Klaviers meiner Tochter. Höhe des Tastenholzes würde 20 mm sein, das ist bei einem Tastenhub von 10 mm vorne auch das absolute Minimum. Schließlich muss der Klaviaturvorderstift in der Taste verschwinden können. Vorteil der 20 mm: dieses Maß bekommt man im Baumarkt. Die Länge ergab sich aus dem zur Verfügung stehenden Platz im Digitalpianogehäuse: 349 mm bzw. 299 mm. Bzw. genau 350 mm inkl. 1 mm Vorderbelag. Die Breiten entsprechen denen eines Standardklaviers. Die Untertasten sind vorne ca. 7/6 mal breiter als die bei einer 7+5 Tastatur. Bei Hornbach gab es Fichtenleisten mit Querschnitt 13,5 x 20 mm (für die Untertasten) und 10 x 20 mm (für die Obertasten).

|Festlegung der Höhen|
| ----------- |
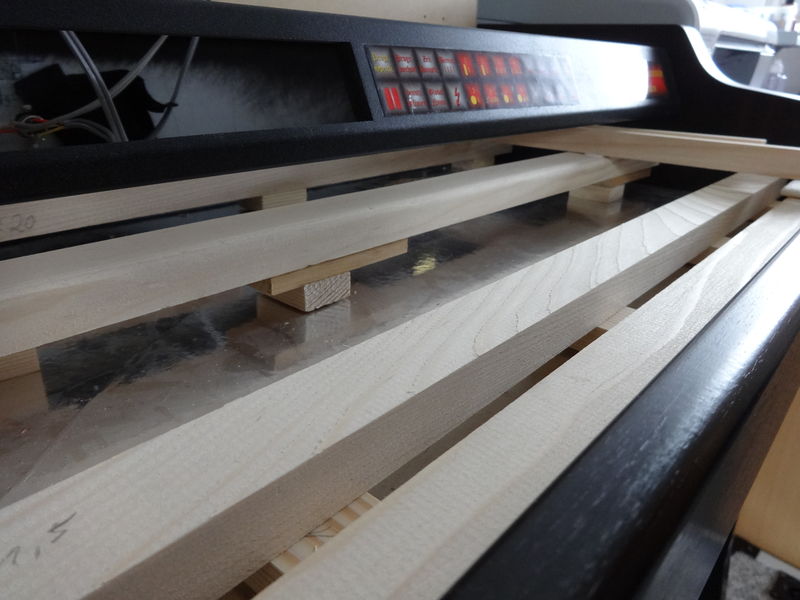
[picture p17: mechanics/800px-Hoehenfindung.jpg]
||

Sehr pfriemelig war es, die Höhen des Waagebalkens, des Ruhebalkens hinten und der vorderen Balken festzulegen. Schließlich war das Gehäuse mit all seinen Maßen vorgegeben. Außerdem sollten die handelsüblichen Holzmaße verwendet werden können. Zu berücksichtigen sind die Höhen des hinteren Tastaturfilzes, der vorderen Druckscheiben sowie der Waagebalkenscheiben. Der Tastenhub soll exakt 10 mm betragen. Wenn man für den Waagebaalken statt 1,0 mm Kasimirscheiben solche mit 1,2 mm nimmt, bedeutet das einen Hubunterschied von 2 * (1,2 - 1,0) = 0,4 mm. Und das kann sich bereits bemerkbar machen! Die Filze für vorne und hinten gibt es ab ca. 4 mm aufwärts in 1 mm Abstufungen. Ich entschied mich für jeweils 5 mm Dicke. Mal sehen, ob alles passen wird...

|Festlegung der Höhen|
| ----------- |
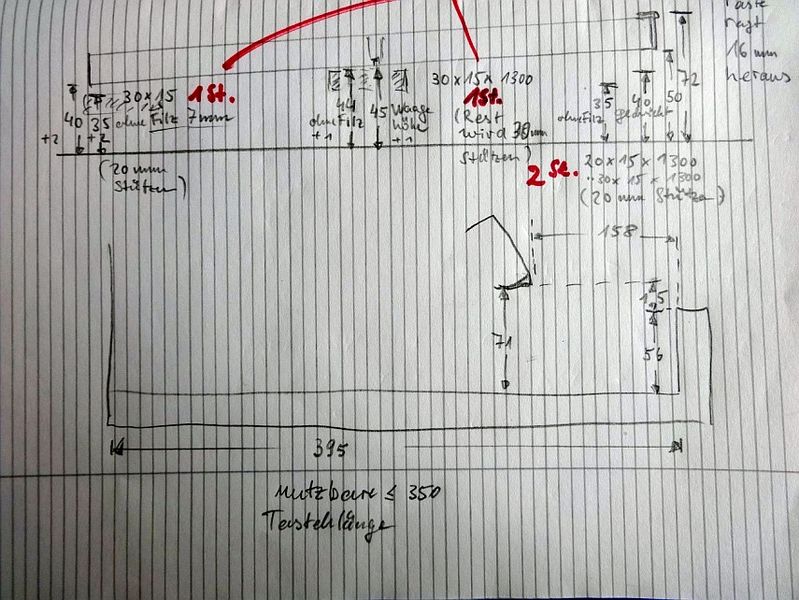
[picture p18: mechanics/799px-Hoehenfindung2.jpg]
||

Nach momentanem Plan sollen die 50 g Niederdruckgewicht vorne allein durch Bleigewichte hinten an den Tasten erreicht werden. Ob damit ein vernünftiges Spielgefühl erreicht werden kann, wird sich zeigen. Da die Mechanik fehlt, ist viel Blei notwendig (ca. 5 kg, ca. 50 g je Taste). Unklar ist, ob der Schwung der 50 g Blei hinten zu einem inakzeptablen Verschleiß des Waagebalkenlochs führen wird. Man könnte es mit Holzleim verstärken oder Gummi verwenden. Man könnte auch über den Tasten den Schwung mit Gummipuffern auffangen und reflektieren, was zu besserer Repetition führen könnte. Eine andere Alternative wäre es, weniger Gewicht und statt dessen zusätzliche Federn zu verwenden. Ich werde mal nur mit Bleigewichten in's Rennen gehen, alles Weitere wird sich zeigen...

|Bleigewichtung und Waagebalkenlöcher|
| ----------- |
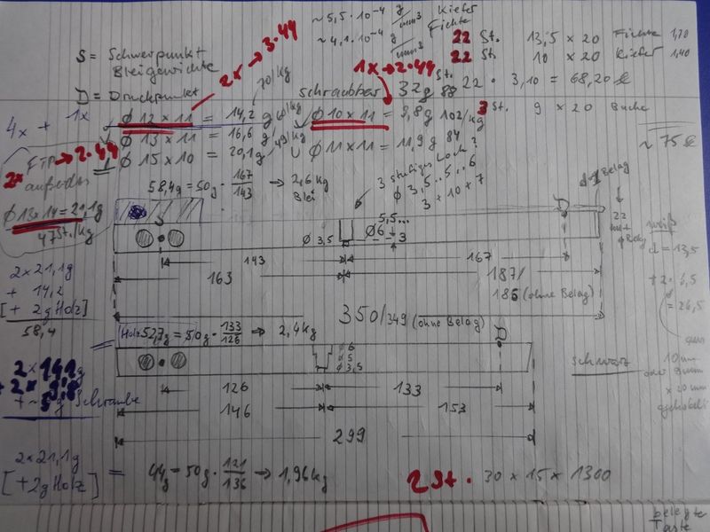
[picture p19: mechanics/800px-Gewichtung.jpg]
||

Das Ausrechnen der Bleigewichte für die Bestellung war auch knifflig. Blei kann man nur kiloweise kaufen. Aus der Dichte von Blei und den Maßen der Bleistöpsel kommt man auf die Anzahl der Stöpsel, die in 1 kg enthalten sein müssten - jedenfalls nach meiner Berechnung. Manche Stöpselgewichte sind ungeeignet. Nicht wegen ihres Einzelgewichtes. Das würde man vielleicht gut einsetzen können. Aber was will mit mit 1 kg in Form von 80 Stöpseln, wenn man 88 (oder 44) Tasten damit ausstatten soll? Entweder hat man 8 Stöpsel zu wenig oder 36 zu viel. Und nur kleine Stöpsel will man auch nicht kaufen, denn dann müsste man sehr viele Löcher bohren. Manche großen Stöpsel, obwohl sie vielleicht das passende Gewicht hätten, lassen sich wiederum nicht für die Obertasten verwenden, da deren Holz nur 10 mm breit ist und die Stöpsel links und rechts zu weit aus der Taste herausstehen würden (bis zum Stöpsel der Nachbartaste). Das Thema Blei ist also abenteuerlich...

### Tasten sägen und fräsen
Die Tasten sägte ich alle von Hand. Die übliche Abschrägung an einer Seite der Obertasten gelang durch schräges Einspannen.

| Auseinandersägen der Obertasten |
| ----------- |
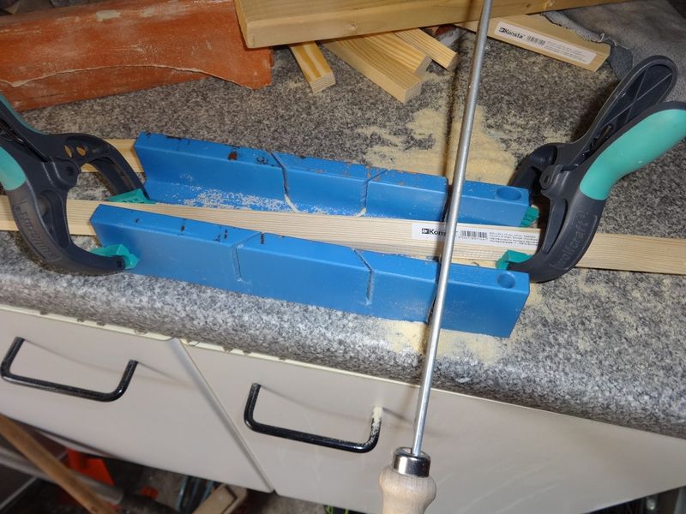
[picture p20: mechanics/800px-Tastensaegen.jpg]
||

Normalerweise dürfte das Fräsen der Vertiefungen für die Garnierungsstreifen vor dem Auseinandersägen der Tasten aus dem Vollen erfolgen. Um Ausfransen zu verhindern, fräste ich zusammengespannte Tastenrohlinge, aber nie bis ganz zum Ende.

| Fräsen der Garnierungsvertiefung |
| ----------- |
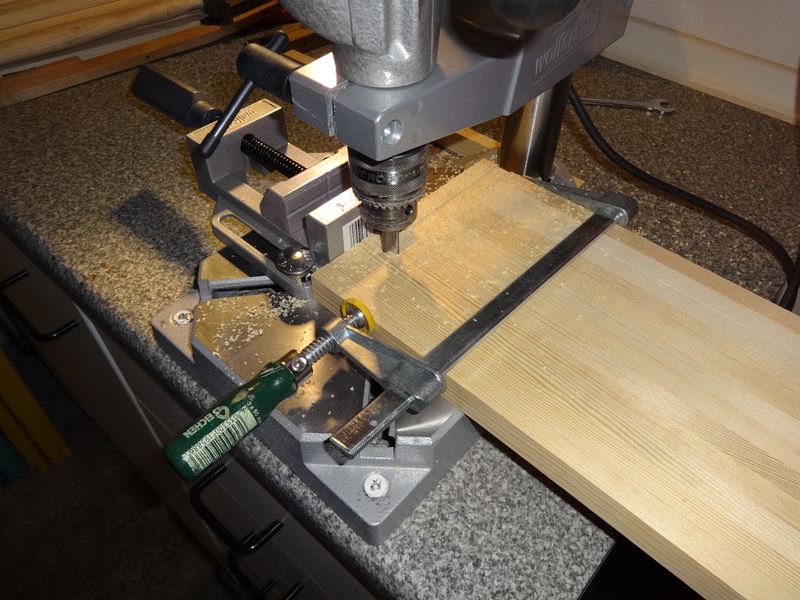
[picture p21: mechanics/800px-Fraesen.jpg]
||

### Das erste Muster Tastenbeläge

Zunächst bestellte ich 4 Tastenbeläge bei Trinckle, und in diesem knalligen Rot kamen sie an:

| Tastenbeläge aus dem 3D-Drucker |
| ----------- |
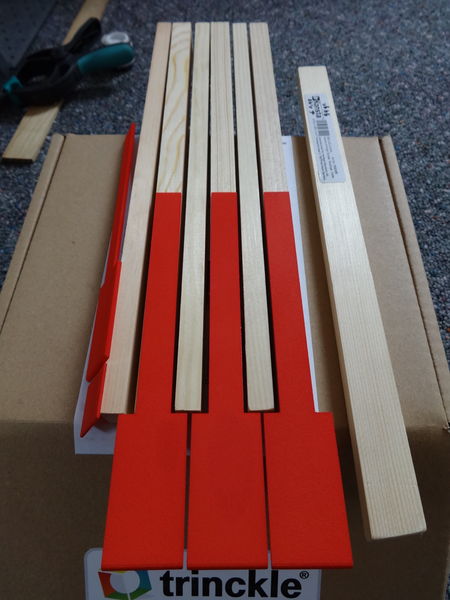
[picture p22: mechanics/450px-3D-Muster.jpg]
||

Nur die Vorderkanten sind bereits im 3D-Design abgerundet. Die Oberfläche ist rauh, und wie von Trinckle gewarnt worden war, dürfte sie nicht ganz abriebfest sein. Zur Haltbarmachung sollten sie noch infiltriert werden, z.B. mit Epoxydharz.

Mittlerweile hat sich herausgestellt, dass sie etwas zu lang sind, hinten ist der Platz zum Teil schon für die Klaviaturbäckchen reserviert. Diese müssen abgesägt werden, der Rest muss kürzer bestellt werden...

### Die Bestellung bei FTP

|Einzukaufende Spezialteile (ohne Klaviaturbäckchen)|
| ----------- |
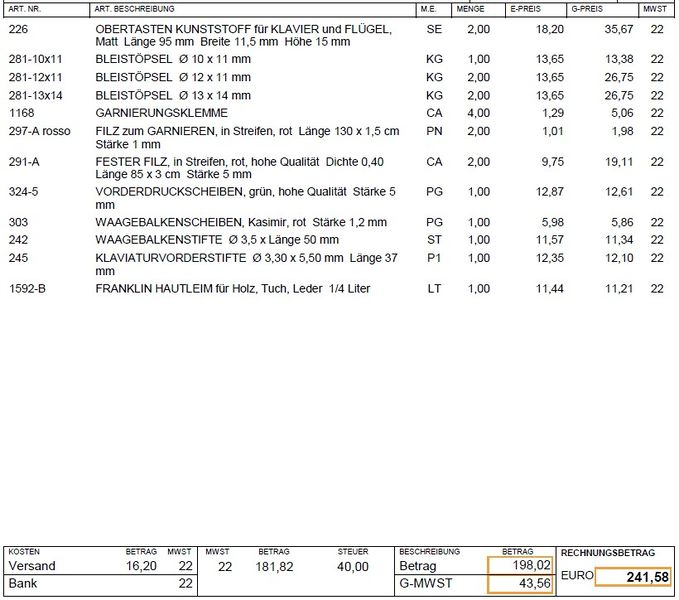
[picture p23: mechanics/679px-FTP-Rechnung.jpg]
||

Dies sind bis auf die Klaviaturbäckchen alle Spezialbauklavierteile, die man braucht (und die fertig käuflich sind). Als Obertasten wählte ich matte, da ich mir von ihnen mehr Halt verspreche, und gerade bei einer 6+6-Tastatur ist guter Halt auf den Obertasten wichtig. Die Garnierungsklemmen helfen beim Garnieren der vorderen Führungslöcher der Tasten. Der feste Filz in Streifen ist für den hinteren Balken gedacht. Der Hautleim ist hoffentlich einer, der durch Dampf aufgeweicht werden kann. Garnierungen sind Verschleißteile und nach Jahren kann eine Erneuerung notwendig werden. Eine Klaviaturdruckzange wird hoffentlich nicht notwendig werden...

Die Teile wurden prompt wie bestellt geliefert. Vicenza (FTP) ist genauso nah wie Braunschweig (Meyne Klaviertechnik GmbH). Irgendwie scheint das Ende der Nationalstaaterei durchaus seine Vorteile zu haben. 

### Untertasten verbreitern

Zum Verbreitern der Untertasten (vorne) verwendete ich 20 x 5 mm Eichenholzleisten, die ich wieder an einer Seite abgeschrägt auseinandersägte. Je ein Plättchen sollte eine Seite der Taste verbreitern. Die eigentlich notwendige Dicke war nicht käuflich, so dass die 5 mm zusätzlich durch entsprechend zugeschnittene Pappscheiben vergrößert werden mussten.

Zunächst klebte ich mir eine Halterung zusammen, die das (oben und vorne) bündige Zusammenleimen von Tastenrohling, 4 Pappscheiben und 2 Eichenplättchen erleichtern würde.

|Tastenhalterung|Zusammenleimen der Untertasten|
| --- | --- |
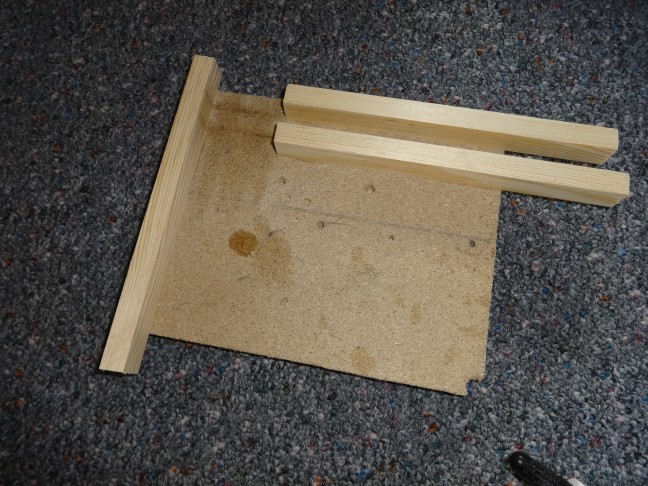
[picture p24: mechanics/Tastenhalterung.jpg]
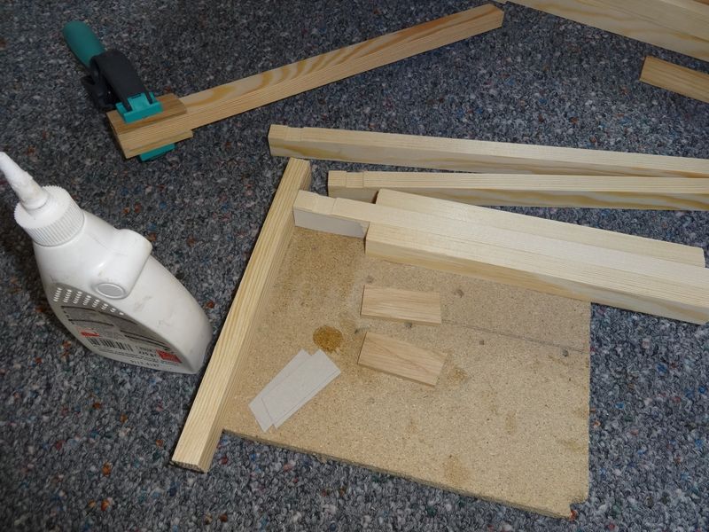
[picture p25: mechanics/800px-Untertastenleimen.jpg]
|||

Damit gelang das exakte Zusammen der Untertasten spielend leicht. Im Vordergrund sieht man 2 der Eichenplättchen und Pappscheiben. Links oben sieht man eine trocknende, zusammengeleimte Untertaste.

Was sich hinterher als ziemlich dumm herausstellte war, dass ich die Tasten zuerst gefräst und dann verbreitert hatte. Die Garnierungsklemmen konnten so nicht richtig angesetzt werden, da die 2 Verbreiterungen im Weg waren. Nach dieser Dummheit musste ich alle Untertasten noch einmal nachfräsen. Mit weniger hohen Verbreiterungen hätte ich das Problem vermeiden könnte. Das wäre möglich gewesen, da die Unterkanten später sowieso nicht zu sehen sein würden.

### Langlöcher

Mangels eines teuren Satzes Langlochfräser in allen möglichen Größen probierte ich es mit Holzbohrern. Man kann nicht voraussagen, was für eine Lochbreite man brauchen wird für einen 3,3 mm Klaviaturvorderstift + 2 x 1,0 mm durch eine Garnierungsklemme zusammengequetschten Filz + max. 0,2 mm Spiel dazwischen. Jedenfalls nicht 5,5 mm. Und schon gar nicht, was für eine Bohrerbreite, da durch Spiel im Maschinenschraubstock und Spiel des Bohrständers das Loch auf jeden Fall breiter als der Bohrer wird. Da geht Probieren über Studieren.

| Versuchsreihe |
| ----------- |
||

Später entschied ich mich dazu, die Langlöcher ganz zu durchbohren, was eher unüblich ist. Ein Grund ist die geringe Höhe meiner Tasten von nur 20 mm, der gewichtigere Grund ist, dass man so von der anderen Seite kontrollieren kann, dass die Garnierungsklemme richtig sitzt und der Filz nicht zu weit in das Loch ragt.

Die besten Resultate kamen mit einem 4,0 mm Holzbohrer und dieser Technik zustande: 

- Bohrtiefe auf Tastenhöhe minus ein paar mm einstellen.
- 3 Löcher setzen.
- Die 2 Brücken zwischen den 3 Löchern mit dem Bohrer entfernen, dabei den Bohrer langsam nach unten bewegen und die Taste immer hin- und herbewegen.
- Bevor die Brücken ganz weg sein, Taste 180° um die vertikale Achse drehen und den Rest der Brücken mit der gleichen Technik entfernen.
- Taste um 180° drehen, diesmal vom Kopf auf den Fuß stellen. Ganz durchbohren und die Durchbohrung auf die ganze Länge erweitern.
- Taste 180° um die vertikale Achse drehen und nochmal hin- und herbewegen.

| 3 Löcher setzen | Brücken entfernen |
| --- | --- |
|  |  |

Am Ende entstanden dabei Langlöcher mit einer Breite um die 5 mm(!). Vielleicht könnte man also mit einem 5,0 mm Langlochfräser optimale Resultate erzielen, ohne umständlich in 4 Orientierungen bohren zu müssen. Vielleicht auch nicht.

### Garnieren

Als Leim nahm ich Titebond Professional Liquid Hide Wood Glue.

Nie hätte ich gedacht, dass man so viel falsch machen kann, wenn man Filz auf Holz kleben will:

- zu viel Leim: der Filz wird hart. Später streifte ich die Klebeseite auf einem Zeitungspapier ab, damit der Filz auf keinen Fall vom Leim ganz durchzogen wird.
- zu wenig Klebstoff hält nicht.
- Filz steht in der Taste über die Garnierungsklemme hinaus: ganz schlecht! Dann hat man am Ende einen breiten Pfropf und der Klaviaturstift stößt beim Eindringen auf Widerstand. Dieser Fall lässt sich nachträglich mit einem Bastelmesser beheben, indem man das Filzende an der gewünschten Stelle durchtrennt und hinterher mit einem Schraubenzieher das festgeklebte Zuviel wegschabt. Das kostet aber Zeit. Von Vorteil war es dabei, dass ich die Tasten ganz durchbohrt hatte. So konnten ich Filz- und Klebstoffreste leichter herausbefördern.
- Filz reicht nicht tief genug in die Taste. Auch schlecht, dann darf man's nochmal machen.

| Garnieren mit Klemme | Filzlängenkontrolle | Noch zu eng |
| --- | --- | --- |
|  |  |  |

Übung macht den Meister, und spätestens nach der 20. Taste hat man den richtigen Dreh gefunden.

Die Streuung der Lochbreiten ist so groß, dass man bei manchen Tasten nicht ohne den Arbeitsschritt mit der Klaviaturdruckzange herumkommt. Wenn das Loch wenige 1/10 mm zu eng ist, so lässt es sich durch Zusammendrücken der Holzränder auf die gewünschte Breite bringen. Die sehr teure Klaviaturdruckzange hatte ich mir wie berichtet gespart. Ich behalf mit mit einer spitzen Flachzange, wobei ich die Außenseiten der Tasten durch ein zwischengelegtes Aluminiumblech vor dem Zangendruck schützte. Die Zange setzte ich so an, dass der Lastarm im Loch parallel zum Lochrand war. Der Lastarm außen hatte folglich einen spitzen Winkel zum Aluminiumblech. Das funktionierte überraschend problemlos.

Der Profi hat wahrscheinlich Garnierungsfilz in verschiedenen Stärken zur Auswahl. Vielleicht entscheidet er sich bei jedem Loch nach vorheriger Prüfung für die passende Stärke?

### Bohren der Waagebalkenlöcher

Die Waagebalkenlöcher müssen sowohl in links-rechts-Richtung als auch in vorne-hinten-Richtung genau sitzen. Die Halterung zum Verbreitern der Untertasten wurde erweitert zu einem Ankörngerät für Waagebalkenlöcher. Ein Metallblech wurde durch 3 Stifte (Schrauben) an die richtige Position fixiert. Dann konnte mit dem Hammer eine spitze Schraube in das Holz an die genau richtige Position getrieben werden. Das Gerät wurde später erweitert, um auch die Obertasten ankörnen zu können.

| Gerät zum Ankörnen der Waagebalkenlöcher |
| ----------- |
|  |

| Mit dem Hammer die spitze Schraube in das Holz schlagen |
| ----------- |
|  |

| Markiert an der gewünschten Position |
| ----------- |
|  |

Das Waagebalkenloch wird von unten (wo die Markierung ist) mit 3,5 mm Durchmesser durch die Taste gebohrt. Die Waagebalkenstifte haben 3,5 mm Durchmesser. Von oben muss es erweitert werden auf mindestens 5 mm (Obertasten), aber nicht ganz durchbohrt. Es sollten mindestens 2 mm mit dem Durchmesser 3,5 mm stehenbleiben.

### Bleigewichte

Mit Hilfe eines Prototypen hatte sich herausgestellt, welche Gewichte an welchen Positionen verwendet werden müssten. Die vorgesehenen Gewichte für die Obertasten erwiesen sich als richtig:

2 Stück ø10 x 11 mm + 2 Stück ø12 x 11 mm. Das heißt (gemessen mit der Küchenwaage) 2 x 8,75 g + 2 x 12,6 g = 42,7 g Gewicht am hinteren Ende der Tasten.

Bei den Untertasten gab es allerdings eine Überraschung. Den 50 g Niederdruckgewicht vorne musste ebenfalls durch 4 Gewichte am hinteren Ende die Waage gehalten werden:

2 Stück ø12 x 11 mm + 2 Stück ø13 x 14 mm. Das heißt 2 x 12,6 g + 2 x 17,2 g = 59,6 g Gewicht am hinteren Ende der Tasten.

Ich würde also noch Bleigewichte der Sorte ø12 x 11 mm (12,6 g) nachbestellen müssen...

Damit die Löcher weit genug hinten gebohrt werden konnten, musste ich zuvor noch Hölzchen auf die Tasten leimen. Zum Bohren der Löcher für die Gewichte fertigte ich 1 Schablone an. Die Taste wurde darin mit einem Waagebalkenstift fixiert. Für Ober- und Untertasten gab es jeweils einen Satz Positionen bestehend aus 1 Stift- und 4 Bohrpositionen in der Schablone. 

| Eine Taste wird in die Bohrschablone geführt |
| ----------- |
|  |

Auf dem Bild erkennt man die 2 x 4 Bohrpositionen für Ober- und Untertasten. 

| Gebohrte Taste | Taste mit eingesetzten Gewichten |
| --- | --- |
|  |  |

Die Gewichte wurden später noch mit Holzleim fixiert.

### Zersägen der Klaviaturbäckchen

Zum Auseinandersägen von Klaviaturbäckchen fertigte ich mir 2 Sägelehren an, eine für breitere Bäckchen (13,5 mm Obertastenbreite) und eine für schmälere (10 mm Untertastenbreite). Das abzusägende Bäckchen wurde mit Hilfe von 2 Waagebalkenstiften auf die richtige links-rechts-Position gebracht, von oben mit einem gebohrten Holz der richtigen Breite fixiert, dann an beiden Seiten abgesägt.

| Sägelehre für breite Bäckchen| Sägen der breiten Klaviaturbäckchen |
| --- | --- |
|  |  |

| 2. Sägelehre für schmale Klaviaturbäckche |
| ----------- |
|  |

### Infiltrieren der 3D-Drucke

Um die Oberflächen der Tastenbeläge haltbar zu machen, bestrich ich sie mit einem dünnflüssigen Epoxydharz, erhältlich zum Beispiel bei Conrad. Bei der Verarbeitung genau an die Gebrauchsanweisung halten, sorgfältig mischen und Schutzhandschuhe tragen!

| Dünnflüssiges Epoxydharz L |
| ----------- |
| |

Eine Küchenwaage mit 1 g Anzeigegenauigkeit half beim Mischen der beiden Komponenten. Ganz kleine Mengen lassen sich damit aber nicht mischen. Zuviel auf einmal sollte man ebenfalls nicht ansetzen, denn ab einer gewissen Zähigkeit lässt sich das Harz nicht mehr schnell auftragen - oder reißt dem Pinsel die Haare heraus. Ich musst drei- oder viermal ansetzen. Jeden Pinsel kann man nach Gebrauch wegwerfen. Das überschüssige Harz darf im Mischgefäß aushärten, danach lässt sich das Mischgefäß wiederverwenden.

| Infiltrieren der Tastenbeläge |
| ----------- |
| |

### Waagebalken und 2 Tastaturvorderbalken bohren

Für die Bohrung der Balken kauft man sich am Besten eine CNC-Maschine. Sollte man das Kleingeld dafür nicht übrig haben, muss man auf andere Weise zum Ziel kommen. Die Löcher sollten auf 1/10 mm genau sitzen. Schon in der Renaissance gelang dies den Instrumentenbauern irgendwie (nur wie?). Im Mittelalter gab es den Zirkelschmied als eigenen Beruf. Ich besorgte mir einen Präzisionszirkel. Ein erster Versuch, mit dem Zirkel direkt auf dem Holz die Bohrlöcher zu setzen führte nicht zum Ziel, sondern zu Waage- und Tastaturbalken, die zwar den Aufbau eines Prototypen ermöglichten, ansonsten aber schrottreif waren: die Streuungen waren viel zu groß.

Beim zweiten Versuch zirkelte ich zunächst auf einem dicken Aluminiumblech, das in seinem früheren Leben mal eine Frontplatte eines 19" Rack-Gehäuses gewesen war. Dabei gab ich mir allerhöchste Mühe, die Löcher haargenau anzureißen und zu bohren.
Gezirkelte und gebohrte Schablone - verwendbar für Waage- und Tastaturvorderbalken
Ein Lochdurchmesser von 3 mm ist geeignet für den Tastaturvorderbalken. Beim Waagebalken müssen in einem 2. Arbeitsschritt die Löcher auf 3,5 mm erweitert werden, was schnell geht (ohne Schablone). Beim Bohren verwendete ich ab dem 2. Schritt immer nur die halbe Schablone für neue Bohrungen, die andere Hälfte wurde mit 3 mm Schrauben an die vorherigen Bohrungen gekoppelt.

| Gezirkelte und gebohrte Schablone - verwendbar für Waage- und Tastaturvorderbalken |
| ----------- |
| |

| Vorhangeln zu neuen Bohrungen mit Hilfe der Metallschablone |
| ----------- |
| |

Das Ergebnis sah augenscheinlich gut aus. Ob es diesmal wirklich verwertbar sein würde?

Als gebranntes Kind übertrug ich die Oktavpositionen (nur die links-rechts-Koordinate) vom Waagebalken auf den Tastaturvorderbalken, jeweils für die Obertasten und die Untertasten. Damit konnte ich beim Bohren mit der Schablone sicherstellen, dass sich keine Ungenauigkeiten aufsummieren.

| Übertragen der Oktavpositionen auf einen Tastaturvorderbalken  |
| ----------- |
| |

| Gebohrter Tastaturvorderbalken |
| ----------- |
| |

### Einbau in das Gehäuse

Auch dies war eine Fummelei mit viel Nervenkitzel. Die Tasten (inkl. noch anzubringender Beläge) sollten vorne ziemlich genau abschließen. Waage- und Tastaturbalken müssen in der links-rechts-Richtung sehr genau aufeinander positioniert sein und in der vorne-hinten-Richtung einigermaßen genau.

| Positionen für Balken und GT2mini Sensorleiste finden |
| ----------- |
| |

Mit 5 mit Gewichten versehenen Tasten konnte das Spielverhalten schon mal einigermaßen bewertet werden. [Video bei YouTube](https://youtu.be/gIU6Z-v1CjM) Die Erdbeschleunigung g = 9,81 m/s2 sollte ohne Reibung dazu führen, dass eine um s = 0,01 m (1 cm) heruntergedrückte Taste in t = Wurzel(2s/g) = 4,5 ms wieder nach oben kommt. Hoch- und runter würde dies ca. 100 Anschläge je Sekunde bedeuten. Theoretisch wäre also auch mit Reibung genügend Reserve drin. Tatsächlich erwies sich die Repetition schneller als bei einem konventionellen Klavier.

| Tastatur weit fortgeschritten |
| ----------- |
| |

Der große Hammer auf dem Bild dient nur als Gewicht zum Herunterdrücken von Tasten, die noch keine Gewichte eingesetzt haben. Der kleine Hammer wird verwendet, nicht ganz gerade stehende Waagebalkenstifte zu korrigieren (mit einem Pufferholz dazwischen). Jede Taste wurde mit viel Liebe genau an ihre Position gesetzt und zu-Fall-gemacht. Deswegen wurden alle Tasten durchnummeriert, obwohl es eigentlich nur 2 verschiedene Arten geben sollte. Das weiße Farbtöpfchen ist mein 50 g Niederdruckgewicht.

| Die Abstände zwischen den Tasten müssen sehr genau sein |
| ----------- |
| |

| Die Abstände zwischen den Tasten müssen sehr genau sein |
| ----------- |
| |

| Vorne zu hohe Ruhepositionen... |
| ----------- |
| |

| ...können durch Unterleimen von Pappe hinten korrigiert werden |
| ----------- |
| |

Die Untertastenbeläge werden mit Fischleim (Hautleim) aufgeleimt. Dann bekommt man sie später mal wieder ab.

| Aufleimen der Untertastenbeläge |
| ----------- |
| |

Für die Obertastenbeläge habe ich weißen Holzleim verwendet, da die Beanspruchung der geleimten Stellen dort stärker ist. Nach dem Aufleimen können die Hölzer vorne mit Lack geschwärzt werden.

| Schwarzlackierte Obertaste |
| ----------- |
| |

### Feinschliff

Irgendwie müssen Trinckle oder ich einen weißen Oberbelag verschlampt haben. Jedenfalls war einer zu wenig da und ich entschied, erst einmal die 4 roten Prototypen an den Rändern zu verwenden. Bei der alten Fatar-Tastatur waren die entsprechenden Tasten mittelbraun. Beim Spielen hat sich herausgestellt, dass die roten Tasten doch in der einen oder anderen Situation hilfreich sein können. Ich werde also noch ein paar rote Beläge 3D-drucken lassen... 

| Die roten Prototypen doch eingebaut |
| ----------- |
| |

Das GT-2 mini will die Tasten und Fußpedale erst einmal kalibrieren. Vorher geht gar nichts. Jede Taste wird dazu einmal gedrückt - statistische Schwankungen beim Drücken inklusive. Deswegen bietet das GT-2 mini eine Nachkalibrierung, bei der jede einzelne Taste eingestellt werden kann. Beim Spielen merkt man, dass die eine oder andere Taste noch etwas gequetscht gehört (Klaviaturdruckzange) oder noch zu-Fall-gemacht werden muss. Hier ist also viel Spielen und Feinschliff gefordert, aber der Spaß hat schon wieder Einzug gehalten.

Der alte Roland JV-1010 hat sehr bald Anschluss an den Midi-Ausgang des GT-2 mini gefunden, sozusagen nach einigen Brechreizattacken, die nach Spielen im mittleren Tastaturbereich mit dem GM-Sound des GT-2 mini aufgetreten waren. Die Presets auf den Plätzen 1-5 verwenden die Sounds des einfachen GM-Soundmoduls. Chorus- und Halleinstellungen scheint sich das GT-2 mini nicht zu merken, obwohl E-Piano ohne Chorus oder Streicher ohne Hall gar nicht anhörbar sind. Es scheint genau einen selbsteinstallbaren Preset-Speicherplatz zu geben, wie man auf Nachfrage bei der sehr hilfsbereiten deutschen QuietTime-Niederlassung erfahren kann. Wie er programmiert wird findet man allerdings nicht in der Bedienungsanleitung. Mir reicht das eine Preset voll und ganz: ich benutze es, um auf Werks-Preset 6 (=stumm) zu schalten, und das ist nach jedem Einschalten sofort ausgewählt. Das Metronom lässt sich so weiterhin nutzen, ohne die grausigen Klänge hören zu müssen.

Bis auf die minderwertigen Sounds versieht das GT-2 mini aber zuverlässig seinen Dienst und macht, was es soll. Nett ist auch der Audio-Eingang und die Audio-Mischfunktion. Zusätzlich zu den Kalibrierungswerten für die einzelnen Tasten gibt es noch einen 5-stufigen globalen Empfindlichkeitswert (unerwarteterweise unter Effects zu finden). Damit bekommt man die Dynamik auf jeden Fall so hin, wie man sie braucht. Das Ausschalten überlebt diese Einstellung allerdings nur im User Preset (s.u. U01).

Der JV-1010 bietet darüberhinaus 3 Stufen für die Tastaturdynamik, wodurch der Stellschrauben fast schon wieder zu viele da sind. Ich habe deswegen zuerst das GT-2 mini intern eingestellt, mit den eigenen Sounds, und dann den JV-1010 hingehängt und mit seinen 3 Stufen angepasst.
Die hintere Stoppleiste

Das hohe Gewicht im hinteren Bereich der Tasten entspricht dem der Klaviermechanik. Es gibt aber einen entscheidenden Unterschied: die Klaviermechanik koppelt ab, wenn die Taste gedrückt ist. Die Gewichte in meiner Tastatur können die Tasten mit ihrer Trägheit hinten nach oben ziehen. Dagegen muss eine Stoppleiste eingebaut werden. Die Tasten müssen also vorne **und** hinten gestoppt werden. Die Stoppleiste dämpft derzeit mit handelsüblichen Fensterdichtungen (weicher als Filz).

| Die hintere Stoppleiste |
| ----------- |
| |

### GT2 versteckte Features

Gehen Sie wie folgt vor:

- Einschalten
- Klang und Einstellungen wählen
- Warten bis das TouchFeld nicht mehr erleuchtet ist
- SOUND drücken und halten bis SET im Display steht
- REC drück um Ihre Wunscheinstellungen abzuspeichern
- Gerät Aus und wieder Einschalten
- Gerät Startet jetzt mit der Anzeige U01 (was so viel bedeutet wie UserSettings01)

INFO: Wenn Sie die Settings wieder löschen wollen, einfach Einschalten und dann den Ein/Aus-Knopf gedrückt halten bis der zu flackern anfängt - dann loslassen - Gerät startet wieder mit den Standardeinstellungen (Anzeige P01)

INFO II: Sollten Sie einfach andere Einstellungen speichern wollen - Gehen Sie einfach die Punkte 1 bis 7 erneut durch - die neuen Einstellungen überschreiben die bisherigen.

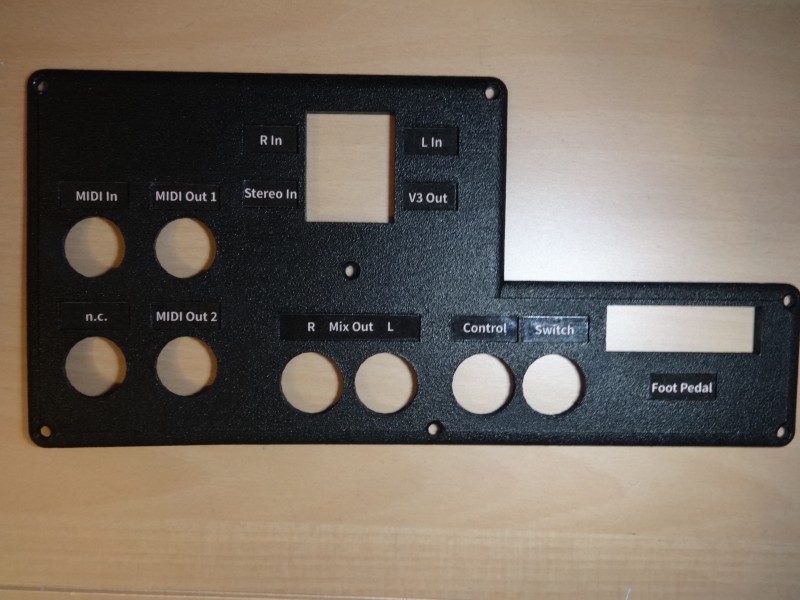
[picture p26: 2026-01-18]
mechanics/hintere_Blende.JPG

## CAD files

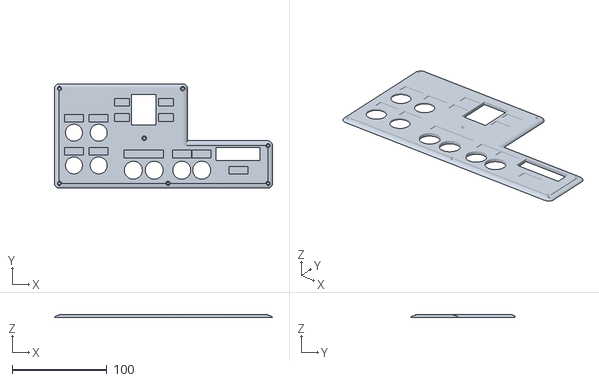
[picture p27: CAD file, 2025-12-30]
mechanics/hintere_Blende.stl
229.5 x 110.0 x 3.00

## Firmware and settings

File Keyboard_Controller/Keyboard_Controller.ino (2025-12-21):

#include <LiquidCrystal.h>
#include <EEPROM.h>
#include <MIDI.h>
#include <MemoryFree.h>
#include "SonorityXXL.h"
#include "Pedal.h"
#include "Display.h"
#include "Velocity.h"
#include "Keyboard_Controller.h"
#include "Scaletune.h"

const char * MY_NAME = "DEMIAN";

MIDI_CREATE_INSTANCE(HardwareSerial, Serial3, midi3);
MIDI_CREATE_INSTANCE(HardwareSerial, Serial2, midi2);

/* data input indicator (MIDI, foot pedal) */
const int led_pin = 13;

/* external switch 1 (damper pedal) pin, last known value and switch type opener/closer */
const int ext_switch_1_pin = 53;
int ext_switch_1_val;
boolean ext_switch_1_opener = false;
/* external switch 2 (pedal) pin, last known value and switch type opener/closer */
//const int ext_switch_2_pin = 51;
//int ext_switch_2_val;
//boolean ext_switch_2_opener = false;
/* external controller pedal, same socket as external switch 2 */
const int external_control_pin = A7; 
const int external_control_maxval = 885; // with 68k popup and 450k controller pedal (log.)
int external_control_val = external_control_maxval; // analog value
int external_val = MIDI_CONTROLLER_MAX; // 0..127 MIDI value
/* enter (red) button pin and last known value */
const int push_btn_enter_pin = 52;
int push_btn_enter_val = HIGH;
/* exit (black) button pin and last known value */
const int push_btn_exit_pin = 50;
int push_btn_exit_val = HIGH;
/* pitch bend wheel input pin and last known value */
const int pitch_wheel_pin = A0;
int pitch_wheel_val;
boolean pitch_wheel_up;
/* modulation wheel input pin and last known value */
const int mod_wheel_pin = A1;
int mod_wheel_val;
boolean mod_wheel_up;
/* master volume control */
const int volume_control_pin = A2;
int volume_control_val = 1023; // 0..1023 analog value
int volume_val = MIDI_CONTROLLER_MAX; // 0..127 MIDI value
/* select */
const int select_pin = A3;
int select_val = -20; // invalid value (outside jitter range) -> set preset according position of knob on init

/* number of current preset, initially the first preset saved in EEPROM */
int preset_number = 0, cancel_number;
Preset currentPreset;
Sound * currentPresetSounds[n_sounds_per_preset] = 
  { &currentPreset.right, &currentPreset.left, &currentPreset.foot, &currentPreset.layer };

const midi::Channel sound_channel = 15;
// right ch. = left ch. + 1, compatible to Matix_to_MIDI project
const midi::Channel right_channel = 2, left_channel = 1, foot_channel = 3, layer_channel = 4; 

/*--------------------------------- setup and main loop ---------------------------------*/

int slice_counter = 0;
const int n_slices = 9;

// settable channels not yet implemented, use the default channels
void readPresetDefaultChannels(int presetNumber, Preset & preset) {
  readPreset(presetNumber, preset);
  preset.left.channel = left_channel;
  preset.right.channel = right_channel;
  preset.foot.channel = foot_channel;
  preset.layer.channel = layer_channel;
}

void setup() {
  Serial.begin(/*9600*/500000); // debugging
  // set up the LCD's number of columns and rows: 
  lcd.begin(lcd_columns, lcd_rows);

  pinMode(led_pin, OUTPUT);
  pinMode(ext_switch_1_pin, INPUT_PULLUP);
  //pinMode(ext_switch_2_pin, INPUT); // ext. 68k pullup, allow 470k logarithmic controller pedal
  pinMode(push_btn_enter_pin, INPUT_PULLUP);
  pinMode(push_btn_exit_pin, INPUT_PULLUP);
  
  setupPedalPins();

  midi::Channel in_channel = 1; // GT-2 mini channel
  midi2.setHandleNoteOn(handleNoteOn);
  midi2.setHandleNoteOff(handleNoteOff);
  midi2.begin(in_channel);
  midi2.setThruFilterMode(midi::Thru::Full);
  midi3.begin(MIDI_CHANNEL_OMNI);
  midi3.setThruFilterMode(midi::Thru::Full);

  ext_switch_1_val = digitalRead(ext_switch_1_pin);
  ext_switch_1_opener = (ext_switch_1_val == LOW);
  //ext_switch_2_val = digitalRead(ext_switch_2_pin);
  //ext_switch_2_opener = (ext_switch_2_val == LOW);

  display(line1, MY_NAME);
  char b[30];
  sprintf(b, "%i bytes free", freeMemory());
  display(line2, b);
  delay(2500);
  //display(line1, "Ext.sw.1:", ext_switch_1_opener?"opener":"closer");
  //display(line2, "Ext.sw.2:", ext_switch_2_opener?"opener":"closer");
  display(line1, "External switch:");
  display(line2, ext_switch_1_opener?"opener":"closer");
  delay(2500);
  // V3 XXL needs these 2 * 2.5 seconds to get ready!
    
  readGlobals();
  sendGlobals(VelocityMapParam);
  readPresetDefaultChannels(preset_number, currentPreset);
  sendPreset(currentPreset);
  dumpSettingsToSerial(); // with 500000 baud takes another ~0.6 seconds
  displayPreset(currentPreset, preset_number);
  
  // disable timers / avoid MIDI jitter
  //TIMSK0 = 0; leave timer 0 enabled so that we still have delay() and millis() but not tone()
  TIMSK1 = 0;
  TIMSK2 = 0;
  TIMSK3 = 0;
  TIMSK4 = 0;
  TIMSK5 = 0;
  Serial.println("Demian ready");
}

/* noise supression by hysteresis */
const int wheel_hysteresis = 3;

// max. time Arduino consumes between 2 calls of loop()
int max_ex_loop_time_ms;
int t_start = -1;

void loop() {
  if (t_start > 0)
    max_ex_loop_time_ms = max(max_ex_loop_time_ms, millis() - t_start);
  
  int inval;
  
  // call this often
  midi2.read();
  midi3.read();

  switch (slice_counter) {
    case 0:
      inval = digitalRead(push_btn_enter_pin);
      if (inval != push_btn_enter_val) {
        push_btn_enter_val = inval;
        if (inval == HIGH)
          process(enterBtn, inval);
      }
      break;
    case 1:
      inval = digitalRead(push_btn_exit_pin);
      if (inval != push_btn_exit_val) {
        push_btn_exit_val = inval;
        if (inval == HIGH)
          process(exitBtn, inval);
      }
      break;
    case 2:
      inval = digitalRead(ext_switch_1_pin);
      if (inval != ext_switch_1_val) 
        handleExtSwitch1(ext_switch_1_val = inval);
      break;
    case 3:
      //inval = digitalRead(ext_switch_2_pin);
      //if (inval != ext_switch_2_val)
      //  handleExtSwitch2(ext_switch_2_val = inval);
      //break;
    case 4:
      inval = analogRead(pitch_wheel_pin);
      if (inval > pitch_wheel_val) {
        if (pitch_wheel_up || inval > pitch_wheel_val + wheel_hysteresis) {
          handlePitchWheel(pitch_wheel_val = inval);
          pitch_wheel_up = true;
        }
      } else if (inval < pitch_wheel_val) {
        if (!pitch_wheel_up || inval < pitch_wheel_val - wheel_hysteresis) {
          handlePitchWheel(pitch_wheel_val = inval);
          pitch_wheel_up = false;
        }
      }
      break;
    case 5:
      inval = analogRead(mod_wheel_pin);
      if (inval > mod_wheel_val) {
        if (mod_wheel_up || inval > mod_wheel_val + wheel_hysteresis) {
          handleModWheel(mod_wheel_val = inval);
          mod_wheel_up = true;
        }
      } else if (inval < mod_wheel_val) {
        if (!mod_wheel_up || inval < mod_wheel_val - wheel_hysteresis) {
          handleModWheel(mod_wheel_val = inval);
          mod_wheel_up = false;
        }
      }
      break;
    case 6:
      inval = analogRead(volume_control_pin);
      // if changed, with +-2 jitter suppression
      if (inval > volume_control_val + 2 || inval < volume_control_val - 2) {
        volume_control_val = inval;
        inval /= 8;
        if (inval != volume_val) {
          sendMasterVolume(volume_val = inval);
        }
      }
      break;
    case 7:
      inval = analogRead(external_control_pin);
      // if changed, with +-2 jitter suppression
      if (inval > external_control_val + 2 || inval < external_control_val - 2) {
        external_control_val = inval;
        // because of the right choice of pullup, values arrive linear enough
        inval = min((long)inval * MIDI_CONTROLLER_MAX / external_control_maxval, MIDI_CONTROLLER_MAX);
        if (inval != external_val) {
          externalControl(external_val = inval);
          //Serial.print("external val "); Serial.println(external_val);
        }
      }
      break;
    case 8:
      inval = analogRead(select_pin);
      // if changed, with +-2 jitter suppression
      if (inval > select_val + 2 || inval < select_val - 2) {
        select_val = inval;
        inval /= 8;
        process(selectKnob, inval);
      }
      break;
  }
  midi2.read();
  midi3.read();
  scanPedal();
  
  slice_counter++;
  if (slice_counter >= n_slices)
    slice_counter = 0;

  // call this often
  midi2.read();
  midi3.read();
  t_start = millis();
}

/*--------------------------------- state event machine ---------------------------------*/

State state = playingPreset;
Sound * editedSound = &currentPreset.right;
byte * param_value ;

/* in sound mode */
int program_number = 0;
enum SoXXLBank current_bank = GeneralMIDI;

/**
 * The state event machine for the user interface.
 * @param event user action
 * @value optional value, meaning depends on event type
 */
void process(Event event, int value) {
  static GlobalParameter global_parameter = VelocityMapParam;
  static ParameterSet parameter_set = CommonParameters;
  static CommonParameter common_parameter = SplitParam;
  static SoundParameter sound_parameter = BankParam;
  static int int_param_value;
  //SoXXLMessage msg;
  switch (state) {

    case playingPreset:
      switch (event) {
        case exitBtn:
          state = playingSound;
          sendGMReset();
          sendCommonParameter(FX1TypeParam, ROOM1);
          sendCommonParameter(FX2TypeParam, CHORUS1);
          sendSound(current_bank, program_number, sound_channel);
          sendSoundParameter(VolumeParam, 100, sound_channel);
          sendSoundParameter(TransposeParam, MIDI_CONTROLLER_MEAN, sound_channel);
          sendSoundParameter(PanParam, MIDI_CONTROLLER_MEAN, sound_channel);
          sendSoundParameter(ReverbSendParam, 10, sound_channel);
          displaySound(current_bank, program_number, false);
          return;
        case enterBtn:
          state = editPreset;
          display(line1, "Edit Preset");
          parameter_set = CommonParameters;
          displayParameterSet(line2, currentPreset, parameter_set);
          return;
        case selectKnob:
          preset_number = value * n_presets / (MIDI_CONTROLLER_MAX+1);
          readPresetDefaultChannels(preset_number, currentPreset);
          sendPreset(currentPreset);
          displayPreset(currentPreset, preset_number);
          return;
      }
      return;
      
    case playingSound: 
      switch (event) {
        case exitBtn:
          state = editGlobals;
          display(line1, "Global Settings");
          setParamValuePointer(global_parameter);
          int_param_value = map_from_byte(global_parameter, *param_value);
          displayGlobalParameter(global_parameter, *param_value);
          return;
        case enterBtn:
          state = selectSound;
          lcd.setCursor(lcd_columns/2 - 1,0);
          lcd.blink();
          return;
        case selectKnob:  
          program_number = value; 
          sendSound(current_bank, program_number, sound_channel);
          displaySound(current_bank, program_number, false);
          return;
      }
      return;
      
    case selectSound:
      switch (event) {
        case exitBtn:
          state = playingSound;
          lcd.noBlink();
          return;
        case pitchWheel:
          // sound select, increment/decrement by 1 or by 10 
          if (handlePitchWheelEvent(value, 0, MIDI_CONTROLLER_MAX, &program_number)) {
            sendSound(current_bank, program_number, sound_channel);
            displaySound(current_bank, program_number, true);
          }
          return;
        case selectKnob:  
          program_number = value; 
          sendSound(current_bank, program_number, sound_channel);
          displaySound(current_bank, program_number, true);
          return;
        case modWheel:
          // bank select, program number remains unchanged
          value = value * n_SoXXL_banks / (MIDI_CONTROLLER_MAX+1);
          SoXXLBank bank = toSoXXLBank(value);
          if (bank != current_bank) {
            current_bank = bank;
            sendSound(current_bank, program_number, sound_channel);
            displaySound(current_bank, program_number, true);
          }
          return;
      }
      return;

    case editGlobals:
      switch (event) {
        case exitBtn:
          saveGlobals();
          state = showInfo;
          displayInfo();
          delay(2000);
          state = playingPreset;
          sendPreset(currentPreset);
          displayPreset(currentPreset, preset_number);
          return;
        case modWheel:
          value = value * n_global_settings / (MIDI_CONTROLLER_MAX+1);
          if (value != global_parameter) {
            global_parameter = (GlobalParameter)value;
            setParamValuePointer(global_parameter);
            int_param_value = map_from_byte(global_parameter, *param_value);
            displayGlobalParameter(global_parameter, *param_value);
          }
          return;
        case pitchWheel:
          // increment/decrement by 1 or by 10 
          {
            int mini, maxi, range;
            getMinMaxRange(global_parameter, mini, maxi, range);
            if (handlePitchWheelEvent(value, mini, maxi, &int_param_value)) {
              *param_value = map_to_byte(global_parameter, int_param_value);
              displayGlobalParameter(global_parameter, *param_value);
              sendGlobals(global_parameter);
            }
          }
          return;
        case selectKnob:
          {
            int mini, maxi, range;
            getMinMaxRange(global_parameter, mini, maxi, range);
            int_param_value = mini + value * range / (MIDI_CONTROLLER_MAX+1) ;
            *param_value = map_to_byte(global_parameter, int_param_value);
            displayGlobalParameter(global_parameter, *param_value);
            sendGlobals(global_parameter);
          }
          return;
      }
      return;

    case showInfo:
      switch (event) {
        case exitBtn:
          state = playingPreset;
          sendPreset(currentPreset);
          displayPreset(currentPreset, preset_number);
          return;
      }
      return;
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

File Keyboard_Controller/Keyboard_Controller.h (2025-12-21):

#include "midi_Defs.h"
// max. value of a MIDI controller
const byte MIDI_CONTROLLER_MAX = 127;
const byte MIDI_CONTROLLER_MEAN = 64;


/*--------------------------------- persistent settings ---------------------------------*/

// the values in a fresh EEPROM
const byte invalid = 0xff;

/*--------- global settings ---------*/
// start address of global settings storage area in EEPROM
const int GlobalSettingsAddress = 0;

const int n_global_settings = 1;

enum GlobalParameter {
  VelocityMapParam
};

struct GlobalSettings {
  byte velocity_map;
  byte reserved2;
  byte reserved3;
  byte reserved4;
  byte reserved5;
  byte reserved6;
  byte reserved7;
  byte reserved8;
  byte reserved9;
};

GlobalSettings globalSettings;

/**
 * Reads global settings from EEPROM.
 * When the EEPROM still contains 0xff defaults,
 * reasonable initial values will be chosen for the global settings.
 */
void readGlobals() {
  // TODO checksum and detection of corrupt data
  byte *b = (byte*)&globalSettings;
  for (int i = 0; i < sizeof(GlobalSettings); i++)
    b[i] = EEPROM.read(GlobalSettingsAddress + i);
  if (globalSettings.velocity_map >= MIDI_CONTROLLER_MAX)
    globalSettings.velocity_map = 0;
}

/**
 * Saves global settings to EEPROM. To maximize EEPROM lifetime only changed values are actually written. 
 */
void saveGlobals() {
  byte *b = (byte*)&globalSettings;
  for (int i = 0; i < sizeof(GlobalSettings); i++) {
    byte original = EEPROM.read(GlobalSettingsAddress + i);
    if (original != b[i])
      EEPROM.write(GlobalSettingsAddress + i, b[i]);
  }
}

/*--------- sound presets ---------*/
const int n_switch_assignable_ctrls = 5;
enum SwitchController {
  NoSwitchCtrl = invalid,
  Sustain = midi::Sustain, // values 00 or 7f
  Sostenuto = midi::Sostenuto, // values 00 or 7f
  Soft = midi::SoftPedal, // values 00 or 7f
  Portamento = midi::Portamento // values 00 or 7f
};

const int n_continuous_assignable_ctrls = 6;
enum ContinuousController {
  NoContCtrl = invalid,
  Modulation = midi::ModulationWheel,
  CutoffFrequency = 0x4A,
  Resonance = 0x47,
  Expression = midi::ExpressionController,
  InverseExpression = 128 + midi::ExpressionController // emulated, for crossfading
};

const int n_pitch_wheel_assignable_ctrls = 3;
enum PitchWheelController {
  NoPitchCtrl = invalid,
  PortamentoControl = midi::PortamentoControl,
  Pitch = 0xfe
};

const int n_presets = 35; // 116 bytes/preset * 35 presets = 4060 bytes EEPROM occupied by presets
const int n_sounds_per_preset = 4; // foot + left hand + right hand [+ right layered]

// start address of preset storage area in EEPROM
const int PresetsAddress = 40;

/* EEPROM structure */
struct Sound {
public:
  byte bank;
  byte program_number;
  byte transpose;
  byte finetune;
  byte volume;
  byte pan;
  byte reserved1;
  byte reverb_send;
  byte effects_send;
  byte reserved2;
  byte cutoff_frequency;
  byte resonance;
  byte attack_time;
  byte decay_time;
  byte release_time;
  byte vibrato_rate;
  byte vibrato_depth;
  byte vibrato_delay;
  byte portamento_time;
  byte reserved4;
  byte reserved5;
  byte mod_wheel_ctrl_no;
  byte pitch_wheel_ctrl_no;
  byte ext_switch_1_ctrl_no;
  byte ext_pedal_ctrl_no;
  byte channel; // not [yet] adjustable but comfortable here
};

// change magic value to force init of each preset
const long magic = 0x2e031fe5;

const int n_pedal_modes = 2;
enum PedalMode { BassPedal, ControllerPedal };

/* EEPROM structure */
struct Preset {
public:
  long magic;
  byte split_point;
  byte pedal_mode;
  byte fx1_type;
  byte fx2_type;
  byte reserved9;
  Sound layer, right, left, foot;
};

void defaultPreset(Preset & preset);
void readPreset(int presetNumber, Preset & preset);
void savePreset(int presetNumber, const Preset & preset);

/**
 * Reads preset from EEPROM.
 * @param presetNumber 0 .. (n_presets - 1)
 */
void readPreset(int presetNumber, Preset & preset) {
  // TODO checksum and detection of corrupt data
  byte *b = (byte*)&preset;
  for (int i = 0; i < sizeof(Preset); i++)
    b[i] = EEPROM.read(PresetsAddress + sizeof(Preset)*presetNumber + i);
  if (preset.magic != magic) 
    defaultPreset(preset);
}

/**
 * Saves preset to EEPROM. To maximize EEPROM lifetime only changed values are actually written. 
 * @param presetNumber 0 .. (n_presets - 1)
 */
void savePreset(int presetNumber, const Preset & preset) {
  byte *b = (byte*)&preset;
  for (int i = 0; i < sizeof(Preset); i++) {
    int address = PresetsAddress + sizeof(Preset)*presetNumber + i;
    byte original = EEPROM.read(address);
    if (original != b[i])
      EEPROM.write(address, b[i]);
  }
}
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

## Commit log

2015-12-29 MemoryFree Arduino library 2015
2016-01-02 fix missing comma leading to wrong sound names of bank B
    [KetronSD2.h]
2016-01-04 MIDI handling complete and 50 % tested for - GT-2 mini keyboard input - wheels - ext. switch 1
2016-01-04 disableld timer interrupts except timer0 to minimize MIDI jitter
    [Keyboard_Controller.ino]
2016-01-06 - pedal hardware modelled - Arduino integrated LED on pin 13 now should blink when MIDI data arrive untested...
2016-01-16 pedal handling implemented, switch mode (pedal as MIDI controller) not yet implemented
2016-01-16 pedal event now switches Arduino board LED, too
2016-01-30 impemented pedal handling in MIDI controller switch mode
2016-02-13 fix too long bass boost SD2 message
    [Keyboard_Controller.ino]
2016-02-20 + global params velocity + filter velocity slopes + offsets
2016-02-20 fixes after tests, some minor errors left + (as expected) pedal diode matrix scan does not yet work (timing?)
    [KetronSD2.h, Keyboard_Controller.h, Keyboard_Controller.ino]
2016-02-21 bug fixes + info display with execution times [ms]
    [Keyboard_Controller.h, Keyboard_Controller.ino, Pedal.h]
2016-02-21 + TVA envelope release time (longer release times necessary for foot play) minor fixes
    [KetronSD2.h, Keyboard_Controller.h, Keyboard_Controller.ino]
2016-02-22 more reasonable init values for SD2 velocity offsets
2016-03-06 HW circuit drawings, not yet complete...
2016-03-13 Arduino based keyboard controller finished + audio mixer circuit
2016-04-17 rearranged pedal keys, no we have left and right sustains and sostenuto pedals fix: after parameter change 1st increment/decrement leads to wrong result
    [Keyboard_Controller.ino]
2019-05-26 switched from Microsoft to LibreOffice
2019-09-09 fix bug after changing left/right channel sequence
    [Keyboard_Controller.ino]
2021-06-07 volume button (re-)implemented
2021-06-08 new audio wiring, new MIDI wiring
2021-06-09 commented out pin 13 Arduino onboard LED code (optimize latency)
    fixed modulation and pitch wheel behaviour in sound select mode (bank and program select)
    now the input Rx3 is forwarded (MIDI through) to Tx3
    and mixed with events by the Demian keyboard controller
    Demian expects note-on/note-off from the keyboard over Rx2 now (formerly Rx3)
    Demian MIDI events are mixed into Tx3
    keyboard events are forwarded (MIDI through) to Tx2
    [Keyboard_Controller.ino]
2021-06-09 new MIDI wiring
2021-06-14 up to Arduino MIDI Library 5.0.2
2021-09-26 several minor bugs fixed
    [Keyboard_Controller.ino]
2022-08-31 routed ext. socket 2 to analog input 7, ext switch and control pedal both supported now
    [extController.ods]
2022-09-25 reset expression value when changing between presets with/without split point
    [Keyboard_Controller.ino]
2022-11-04 started transfer of docs from vermaschung.de...
2022-12-26 electronics and software docs migrated from vermaschung.de to Markdown
2024-03-23 checked the sound bank's name arrays + corrected
    [SonorityXXL.h]
2024-03-24 bugs fix after testing
    [Keyboard_Controller.h, Keyboard_Controller.ino, SonorityXXL.h]
2024-04-01 Fix missing display of right keyb. layer param set
    [Keyboard_Controller.ino]
2024-04-13 simplified state-event machine by use of new HW button
2024-08-24 pedal can now cycle bank up *and* down, corrected too long sound names (reason for crashes)
    [Keyboard_Controller.ino, SonorityXXL.h]
2024-08-25 bug fixes, clearer code, safer UI
    [Keyboard_Controller.h, Keyboard_Controller.ino]
2024-08-27 fixed global effects control, set EQs to flat (which is not the V3 XXL default!)
    [Keyboard_Controller.ino, SonorityXXL.h]
2024-08-27 fix common parameter select bug
    [Keyboard_Controller.h, Keyboard_Controller.ino]
2024-10-06 implemented first global setting: normal/hard velocity map
2025-01-01 - reverb and volume adjust for sound mode - leaving preset edit state without saving improved - normal_min7.h velocity map corrected (was min 0, not 7)
    [Keyboard_Controller.ino]
2025-04-13 more elaborated velocity map implementation
2025-05-04 Complete rework of MIDI controllers for V3 Sound modules
    [Keyboard_Controller.h, Keyboard_Controller.ino]
2025-05-18 fixed serial dump and finished documentation after MIDI controller rework
    [Keyboard_Controller.ino]
2025-06-21 audio wiring changed (now with 3.5 mm stero input and 6.3 mm stereo output)
2025-10-31 changed internal switch to internal continous control
2025-10-31 changed int. switch to continuous controller, update documentation
2025-11-28 red push button in sound mode pressed -> bank select via mod. wheel
2025-12-05 restored the old selectSound code for input via pitch and modulation wheels (sound and bank)
2025-12-30 back plate for 3D printing (auto-repaired by rapidobject online)
    [hintere_Blende.stl]
2026-01-18 added back plate texts and photo
